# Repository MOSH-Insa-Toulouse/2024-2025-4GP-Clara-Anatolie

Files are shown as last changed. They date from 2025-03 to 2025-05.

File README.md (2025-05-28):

# 2024-2025 : Projet de capteur low-tech en graphite - Anatolie Blanc & Clara Jeandenans

## SOMMAIRE

- [SOMMAIRE](#sommaire)
- [Contexte](#contexte)
- [Livrables](#livrables)
- [Matériel nécessaire](#matériel-nécessaire)
- [Simulation électronique du capteur sous LTSpice](#simulation-électronique-du-capteur-sous-ltspice)
- [Design du PCB sous KiCad](#design-du-pcb-sous-kicad)
- [Réalisation du shield](#réalisation-du-shield)
- [Code Arduino](#code-arduino)
- [Tentatives de résolution des problèmes](#tentatives-de-résolution-des-problèmes)
- [Application Android](#application-android)
- [Banc de test](#banc-de-test)
- [Datasheet](#datasheet)
- [Conclusions et analyse critique du projet](#conclusions-et-analyse-critique-du-projet)
- [Contacts](#contacts)

## Contexte

&nbsp;&nbsp;&nbsp;&nbsp;&nbsp;&nbsp;Dans le cadre de l'UF "Du capteur au banc de test" effectué en 4ème année au département du Génie Physique de l’INSA Toulouse, nous avons développé un dispositif permettant de mesurer la contrainte appliquée sur un capteur graphite. Ce dernier est basé sur l'article "Pencil Drawn Strain Gauges and Chemiresistors on Paper" (Cheng-Wei Lin*, Zhibo Zhao*, Jaemyung Kim & Jiaxing Huang). Il est simplement composé d'un bout de papier sur lequel on vient déposer du graphite à l'aide d'un crayon à papier. La couche de graphite est constituée de particules reliées entre elles. En déformant le papier, la disposition des particules varie. En fonction du sens de flexion du papier, la déformation peut être soit une traction soit une compression. Dans le cas d’une traction, les particules de graphique s’écartent, la résistance augmente. Dans le cas d’une compression, les particules se rapprochent et la résistance diminue. Ainsi donc, ce système granulaire subit une modification de résistance et de conductance selon la contrainte exercée. Grâce à cela, nous pouvons remonter à la déformation, telle une jauge de contrainte traditionnelle.

Afin de réaliser ce dispositif permettant la mesure de déformation à partir d'un capteur low-tech, il nous faut suivre différentes étapes : simulations électroniques, design du PCB, code arduino et réalisation de la datasheet.

Ici, nous faisons un point de tout ce qui a été fait dans le cadre de ce projet.

## Livrables

Plusieurs livrables sont attendus :

- **Un shield PCB connecté à une carte arduino UNO** avec différents composants : un capteur graphite, un amplificateur transimpédance, un module bluetooth, un écran OLED, un flex sensor commercial, un potentiomètre digital, un encodeur rotatoire. D'autres composants peuvent être implémentés. Nous avons opté pour l'ajout d'un servo motor ;
- **Un code arduino** qui gère les différents composants cités précédemments (mesures de contraintes, échanges bluetooth et OLED, potentiomètre digital et boutons) ;
- **Une application Android** (sous MIT App Inventor) interfaçant le PCB et le code Arduino correspondant;
- **Une datasheet du capteur** reprenant toutes ses caractéristiques ainsi que ses tests.

## Matériel nécessaire

Afin de réaliser notre dispositif électronique, nous avons eu besoin de :

*Pour le montage amplificateur transimpédance :*

- Résistances : une de 1 kΩ, une de 10 kΩ et deux de 100 kΩ - une troisième de 100 kΩ peut être prévue, mais peut aussi être substituée par une résistance variable (le potentiomètre digital), choix que l'on a fait ;
- Potentiomètre digital MCP41050 et son support ;
- Amplificateur opérationnel LTC1050 et son support ;
- Capacités : trois de 100 nF et une de 1 μF.

*Pour le reste du dispositif :*

- Arduino Uno et son câble d’alimentation ;
- Résistance : une de 47kΩ pour le flex sensor ;
- Module Bluetooth HC05 ;
- Ecran OLED de dimension 128*64 ;
- Flex sensor ;
- Servo motor ;
- Encodeur rotatoire ;
- Capteur graphite et 2 pinces crocodiles ;
- 20 sockets ;
- 35 headers.

## Simulation électronique du capteur sous LTSpice

&nbsp;&nbsp;&nbsp;&nbsp;&nbsp;&nbsp;Notre capteur de graphite possède une résistance variable de l'ordre du gigaohm. Le courant généré, lorsque l'on applique une tension de 5V aux bornes du capteur, est très faible (de l'ordre de la dizaine de nanoampères). Ainsi, pour récupérer et pouvoir analyser ce signal, nous devons d’abord l'amplifier. C'est pourquoi nous avons utilisé un montage transimpédance, constitué d'un amplificateur opérationnel (AOP) pour fournir un signal en tension suffisant au convertisseur analogique-numérique (ADC) d'une carte Arduino UNO.

***Description du montage amplificateur transimpédance***

Nous avons testé ce montage sur le logiciel LTspice :

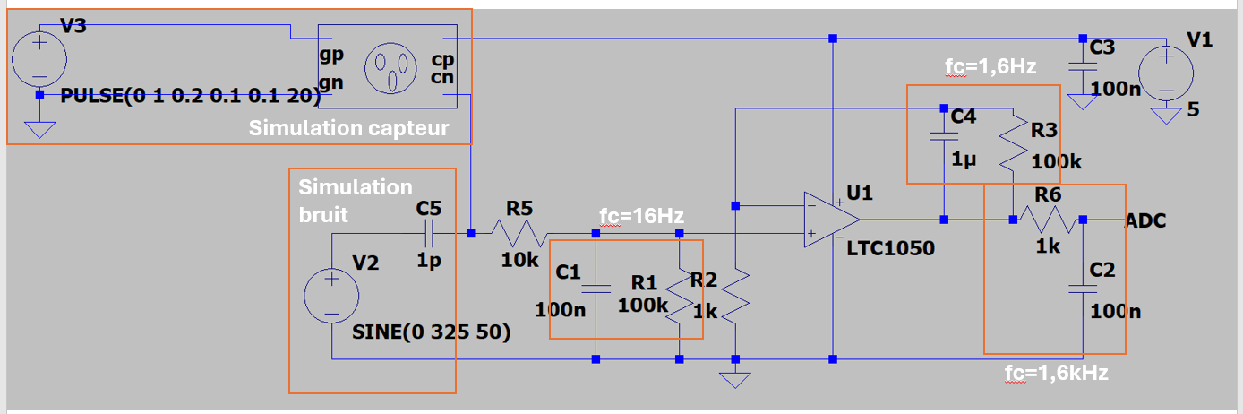
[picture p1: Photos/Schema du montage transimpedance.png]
montage_capteur_graphite


Pour construire ce montage, nous nous sommes basées sur ce schéma ci :

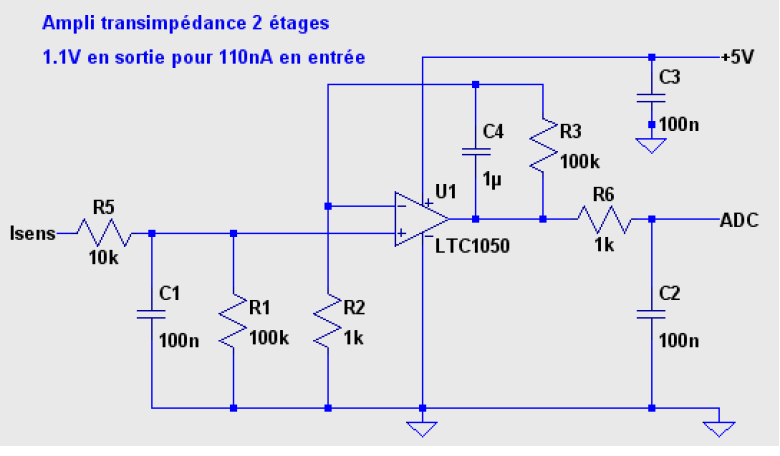
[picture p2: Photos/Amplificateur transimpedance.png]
montage_transimpédance


Concernant le choix de notre AOP, celui-ci devait être capable d'accepter en entrée un très faible courant. Il doit également avoir un offset de tension très faible afin de ne pas fausser les valeurs de tension transmises à l'ADC, puis analysées. Ainsi, nous avons choisi l’AOP nommé LTC 1050.

A ce circuit amplificateur, nous avons ajouté trois filtres pour améliorer notre signal :

- à l'entrée, un filtre passe-bas passif (R5,C1) ayant une fréquence de coupure de 16 Hz. Il permet de filtrer les bruits en courant sur le signal sortant du capteur ;
- un deuxième filtre passe-bas ayant une fréquence de coupure de 1.6 Hz (R3,C4) couplé à l'AOP. Ce filtre actif permet de filtrer la composante du bruit à 50 Hz provenant du réseau électrique ;
- à la sortie de l'amplificateur, un dernier filtre (R6,C2) ayant une fréquence de coupure de 1.6 kHz et permettant de filtrer le bruit lié au traitement opéré par l'amplificateur (bruits des alimentation, de l'horloge, etc...).

De plus, nous avons placé la capacité C3 de sorte à ce qu'elle filtre le bruit de l'alimentation. La résistance R5 en entrée, en plus de former avec la capacité C1 un filtre éliminant les bruits en tension, protège l'AOP contre les décharges électrostatiques. La résistance R1 sert de résistance de shunt entre la source de courant et la masse. La résistance R2 sera remplacé plus tard par un potentiomètre digital afin de régler le gain de l’AOP en fonction de nos besoins.

***Simulations réalisées sous LTSpice***

Pour savoir si nos filtres étaient efficients, nous avons testé notre circuit le logiciel LTSpice, en deux temps.
D'abord, nous avons effectué une première simulation en régime transitoire pour vérifier que l'amplification soit bien effective. Voici la réponse obtenue :

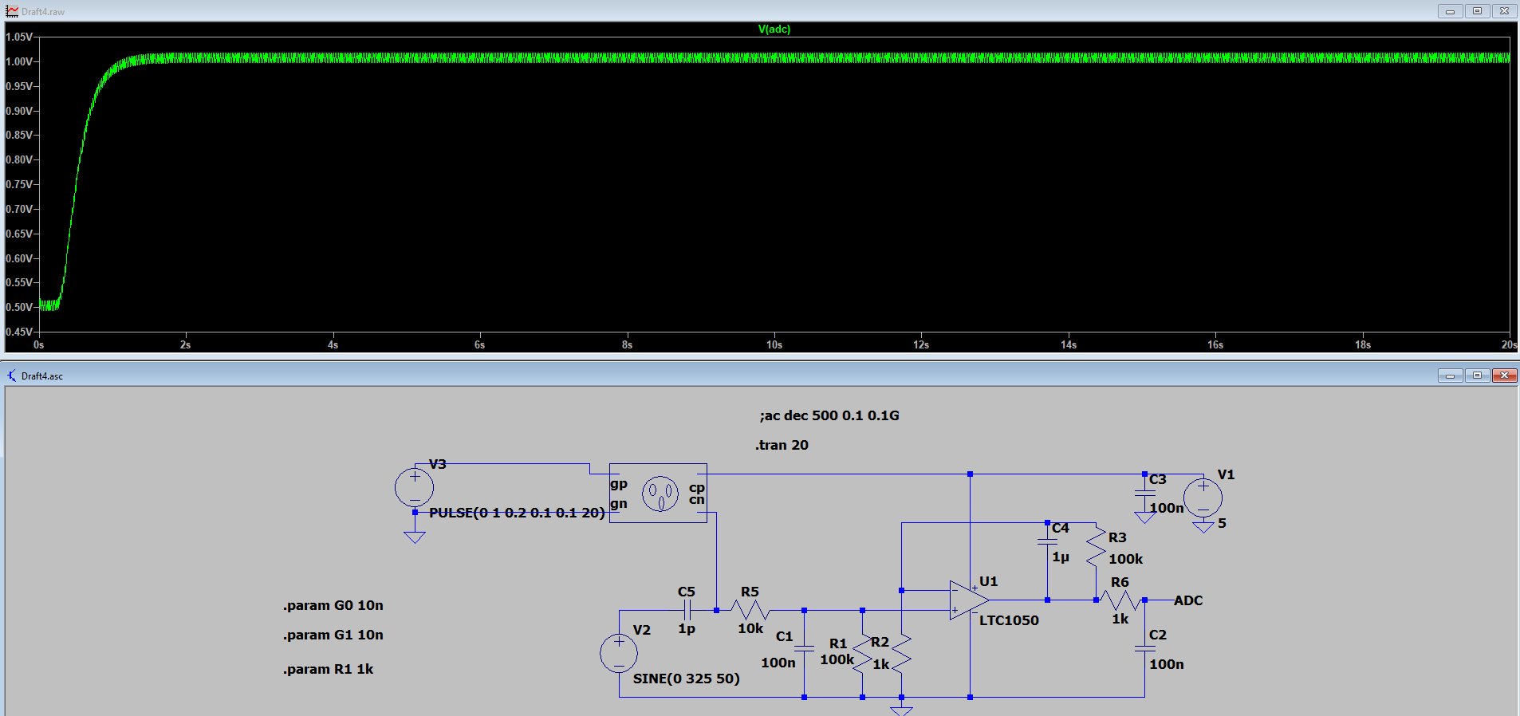
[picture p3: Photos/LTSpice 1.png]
Test_En_Transitoire


Comme on peut le constater sur le graphe, le signal est bien amplifié à 1 V. L'Arduino pourra donc l'interpréter.

Ensuite, nous avons effectué une seconde simulation, afin d'observer la réponse à un courant alternatif et ainsi de vérifier que le signal est bien filtré.

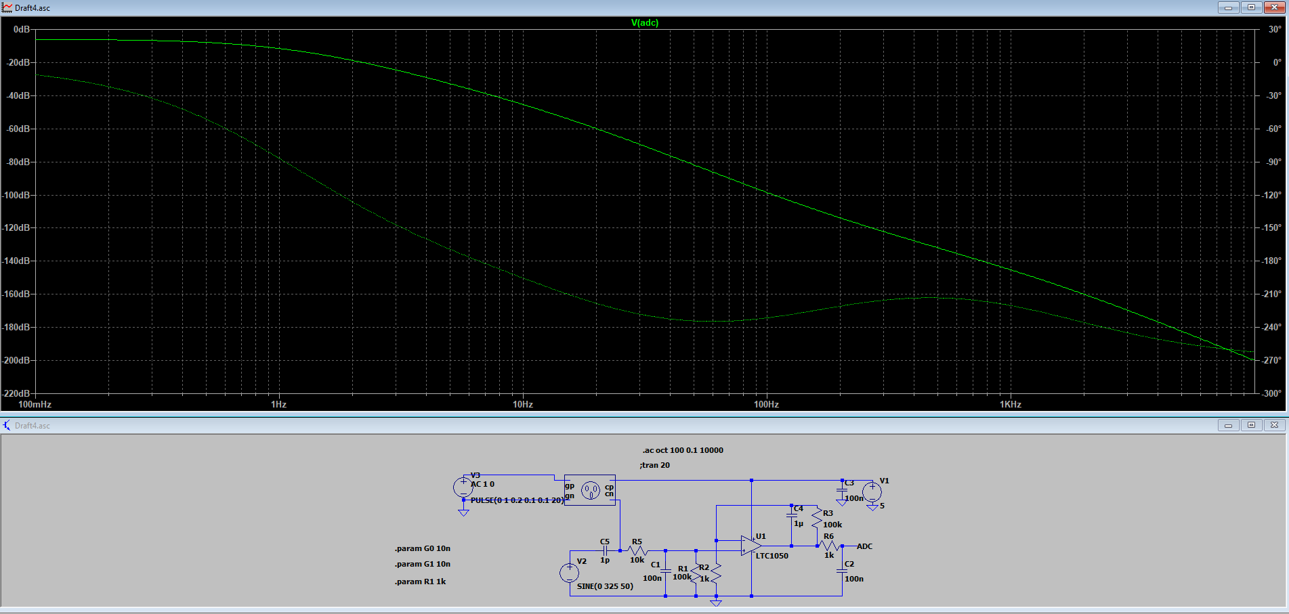
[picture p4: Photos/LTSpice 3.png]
Test_En_AC


Comme on peut le constater ci-dessous, le signal paraît être filtré successivement par les 3 filtres. Le bruit est atténué d’environ 72dB à 50Hz. Le montage est performant.

## Design du PCB sous KiCad

&nbsp;&nbsp;&nbsp;&nbsp;&nbsp;&nbsp;Afin de réaliser notre PCB, nous avons reproduit le circuit précédent sur Kicad 9.0. Nous avons remplacé la résistance R2 par un potentiomètre numérique afin de pouvoir faire varier le gain de notre AOP. De plus, nous avons rajouté divers composants afin de pouvoir mesurer efficacement la valeur de notre capteur graphite et comparer les résultats obtenus :

- un flexsensor servant de témoin, afin de pouvoir comparer nos mesures avec celle du capteur graphite
- un module bluetooth HC-05 afin de pouvoir communiquer avec notre circuit depuis notre téléphone depuis une application mobile que avons codée nous-même
- un écran OLED ainsi qu’un encodeur rotatoire pour pouvoir visualiser le résultat de nos mesures et pouvoir naviguer simplement dans les différents menus servant à réaliser diverses mesures
- un servomotor.

Tous nos composants ont été installés sur un shield d'Arduino UNO.

Nous avons débuté par la création d'une librairie de symboles comportant tous les différents composants. Puis, nous avons procédé à la réalisation de la schématique électrique de l'ensemble du montage sur Kicad. Voici le schéma électrique de l'ensemble de notre montage :

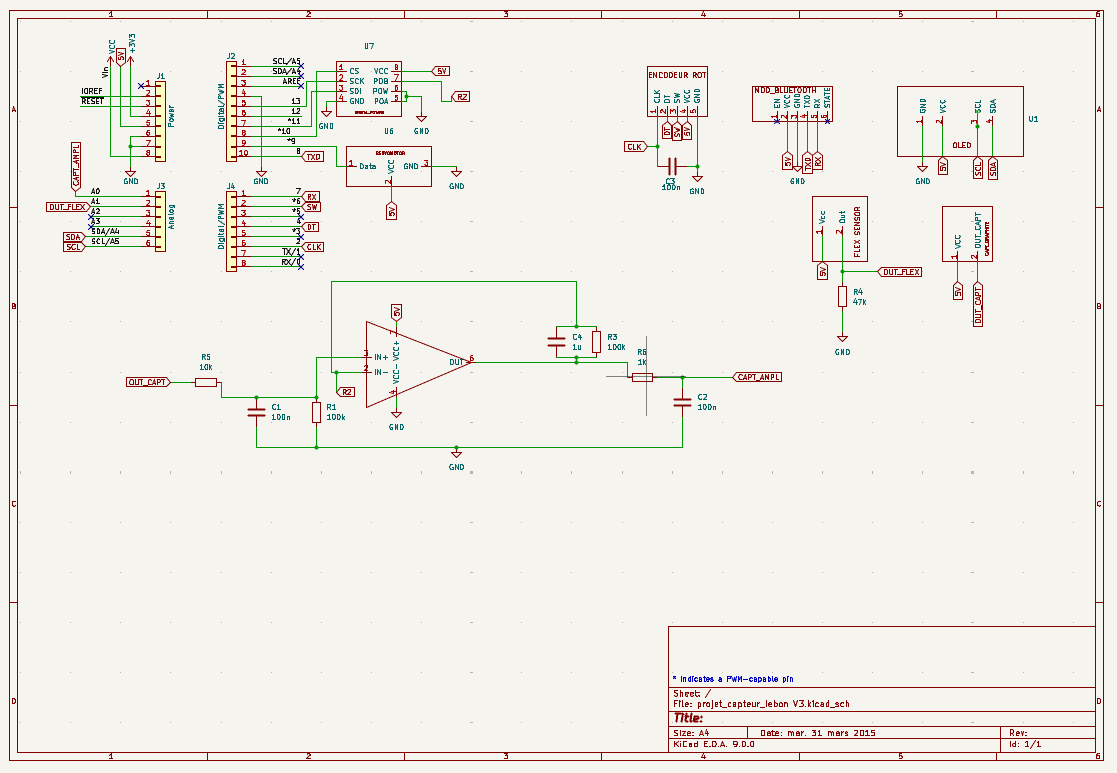
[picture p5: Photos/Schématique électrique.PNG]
Schema_elec_Kicad


Nous avons ensuite réalisé les empreintes de nos composants en respectant certaines dimensions, en vue de l'impression du PCB (diamètre des trous, forme des empreintes, etc.).Nous sommes ensuite passées à la disposition des composants sur le PCB : une étape complexe car il faut faire des compromis afin d'obtenir le placement le plus efficace (en considérant les connexions entre composants, en évitant d'avoir recours aux vias, etc.). L'image ci-dessous correspond au résultat final de notre PCB :

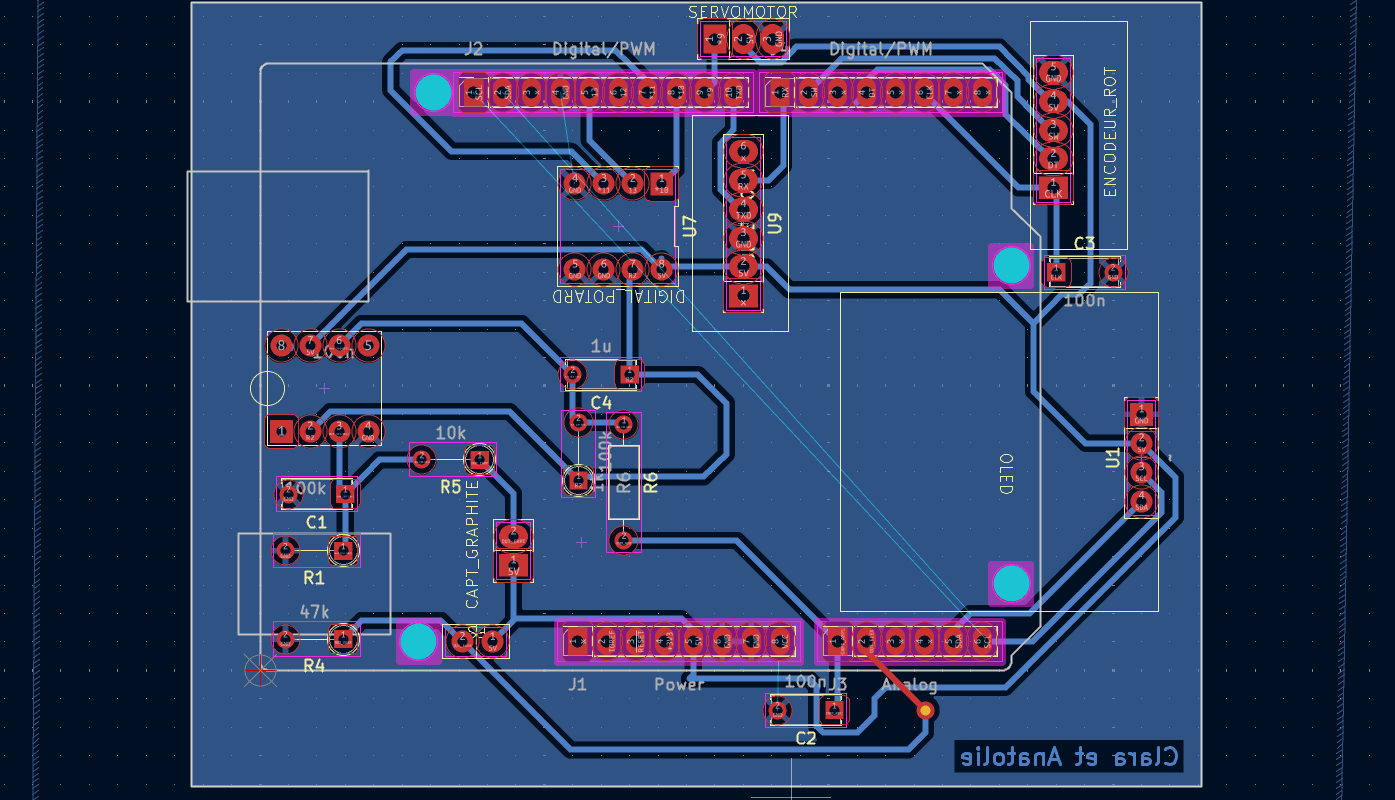
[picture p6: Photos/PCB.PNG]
PCB_Kicad


Nous avons aussi fait en sorte que les composants ne se touchent pas à l’aide du rendu 3D que voici :

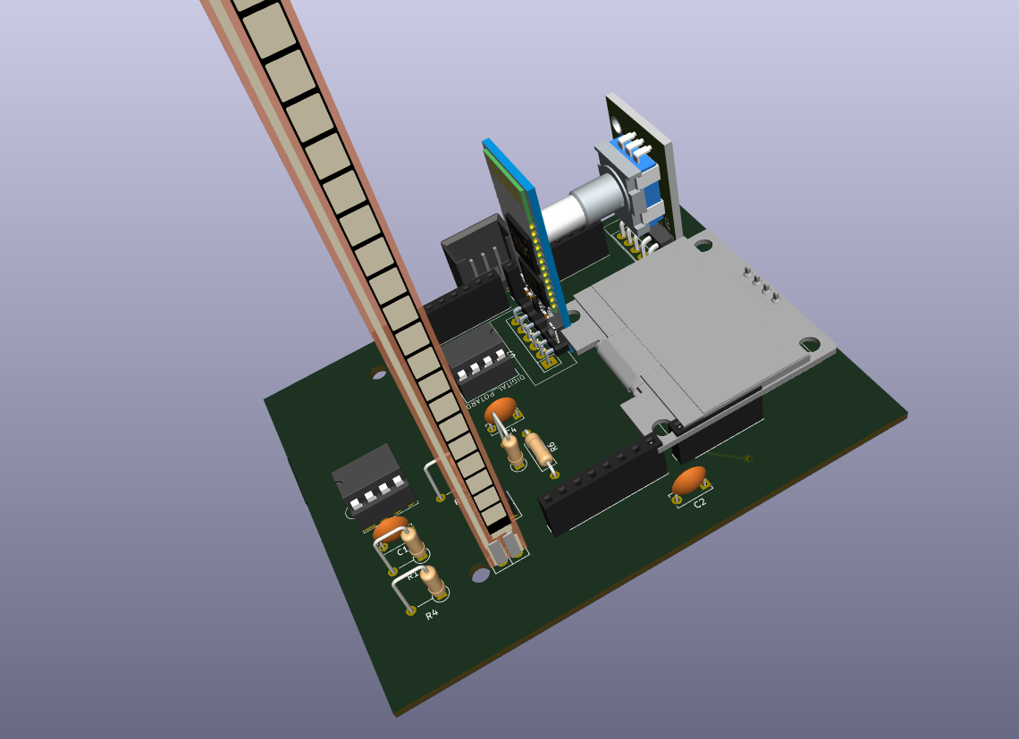
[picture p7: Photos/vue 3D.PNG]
3D_PCB_Kicad


Les fichiers KiCad sont disponibles dans le dossier [KiCad](https://github.com/MOSH-Insa-Toulouse/2024-2025-4GP-Clara-Anatolie/tree/3c948c7d110ff542ae939aa06793f8daed436087/KiCad/projet_capteur_lebon%20-%20VERSION%203)

## Réalisation du shield

&nbsp;&nbsp;&nbsp;&nbsp;&nbsp;&nbsp;Une fois notre PCB réalisé sur Kicad, nous avons pu passer à la réalisation physique de notre PCB. Voici les étapes de fabrication réalisées, avec l'aide de Cathy Crouzet (un grand merci à elle qui a pris le temps de tirer notre PCB et nous expliquer le processus de fabrication !) :

- Étape 0 (importante !) : vérification du PCB sous KiCad ;

- Étape 1 : édition du masque de gravure de notre PCB sous KiCad ;

- Étape 2 : insolation UV d'une plaquette d'époxy recouverte d'une couche de cuivre et de résine photosensible ;

- Étape 3 : immersion de la plaquette dans un révélateur afin d'éliminer la résine non-insolée ;

- Étape 4 : immersion de la plaquette dans du perchlorure de fer pour graver les pistes ;

- Étape 5 : nettoyage de la plaquette avec de l'acétone pour retirer la résine restante.

Nous avons ensuite pu réaliser le perçage de notre plaquette et y souder nos divers composants selon le schéma du PCB obtenu sur Kicad.

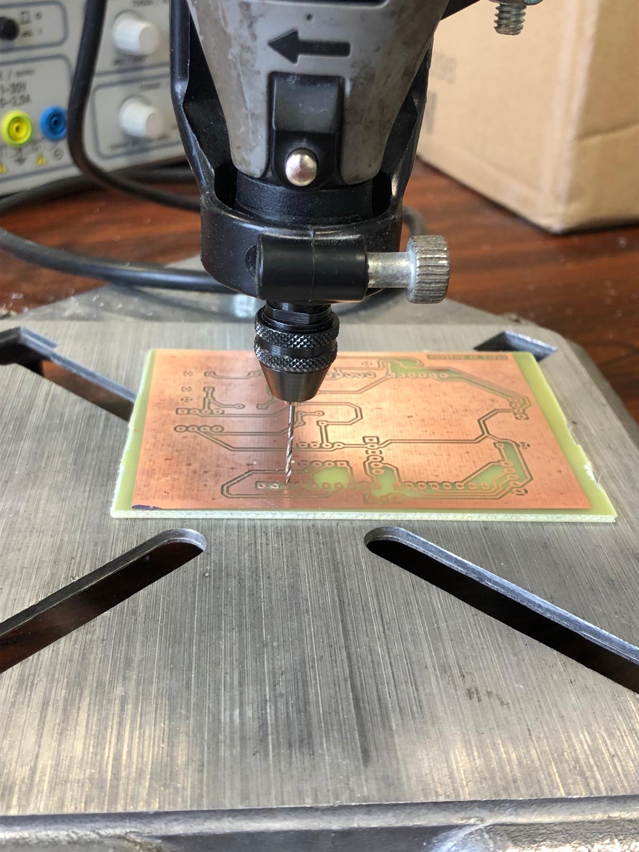
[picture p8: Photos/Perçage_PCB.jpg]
Perçage_du_PCB


Voici le résultat final de notre PCB :

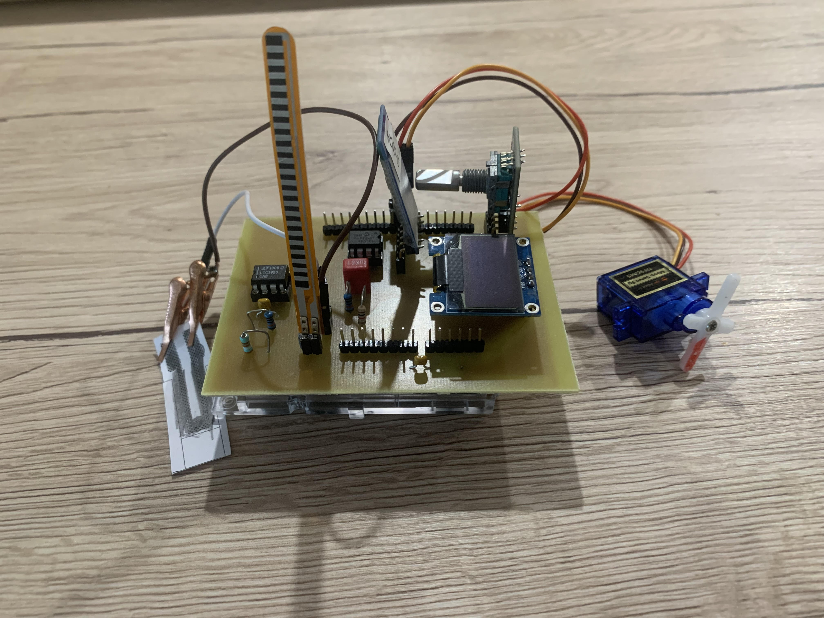
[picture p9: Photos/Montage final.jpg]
Plaquette_finale


L’assemblage de la plaquette et l’Arduino a été plus compliqué que prévu. En effet, l'ensemble de nos trous étaient légèrement décalés les uns par rapport aux autres. Le problème semblait venir de l’étape de perçage.

De plus, le header connecté à la pin A0, qui devait servir pour le capteur de graphite, ne fonctionne pas. Nous avons donc décidé d'utiliser la pin A1, qui servira donc à récupérer les données du flex sensor et du capteur de graphite. Il nous suffit alors de brancher/débrancher les capteurs pour les échanger. Malheureusement, le signal provenant du capteur de graphite ne sera donc pas filtré et amplifié.

## Code Arduino

&nbsp;&nbsp;&nbsp;&nbsp;&nbsp;&nbsp;Nous avons utilisé l'IDE Arduino 2.3.4 . Plusieurs fichiers de test sont disponibles dans le [dossier Arduino](https://github.com/MOSH-Insa-Toulouse/2024-2025-4GP-Clara-Anatolie/tree/main/Code%20Arduino/Codes_Arduino_Tests).

Pour le [fichier principal](https://github.com/MOSH-Insa-Toulouse/2024-2025-4GP-Clara-Anatolie/tree/main/Code%20Arduino/Projet_capteur), nous avions prévu de faire une calibration du potentiomètre digital en fonction de la valeur mesurée par le capteur graphite. Ensuite, le menu de l'écran OLED propose 3 options :
- Utiliser le flex sensor
- Utiliser le capteur graphite
- Utiliser le Servo moteur

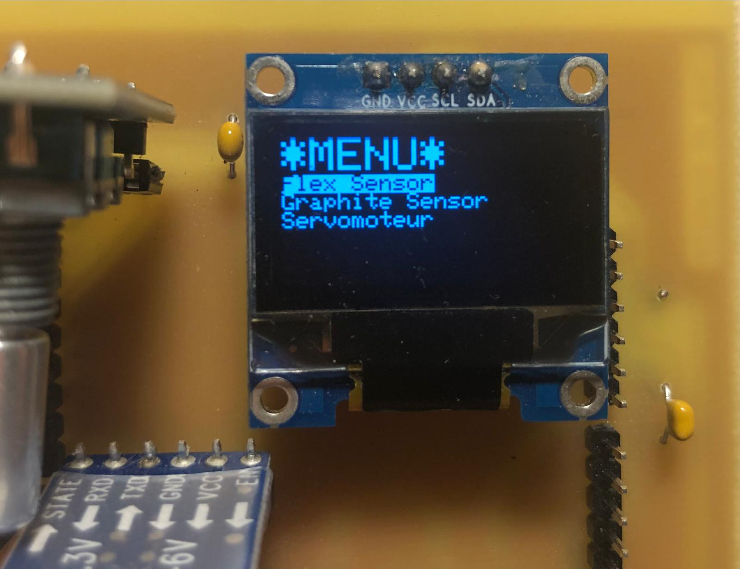
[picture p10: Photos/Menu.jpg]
Menu


Le choix se fait grâce à l'encodeur rotatoire. En tournant, on peut passer sur les différentes options puis en sélectionner une en appuyant sur l'encodeur. Cet appui sert également à sortir du menu selectionné.

L'option concernant le flex sensor récupère sa valeur et l'écrit sur l'OLED. L'option "Graphite Sensor" récupère sa valeur de résistance et l'affiche aussi sur l'écran. Enfin, la dernière option déplace le servo moteur en fonction de la valeur du flex sensor.

Le calcul de la résistance du capteur en graphite se fait avec la formule : $Res=R1*(1+\frac{R3}{R2})*\frac{Vcc}{Vadc}-R1-R5$

Dans notre cas, la résistance R2 est variable : c'est celle du potentiomètre digital qui est calculé avec : $R2=\frac{47500*pos}{256}+125$, où $47500$ correspond à la valeur de résistance maximale de notre MCP41050 et $pos$ la position du potentiomètre parmi les 256 valeurs.

Le module bluetooth HC-05 reçoit également les valeurs du capteur graphite et affiche un graphe.

## Tentatives de résolution des problèmes

&nbsp;&nbsp;&nbsp;&nbsp;&nbsp;&nbsp;Lorsque nous tentons de récupérer la valeur de la résistance du capteur graphite, nous obtenons une valeur infinie. En effet, la tension de sortie de ce capteur est nulle. Nous avons vérifié toutes les connexions sur le PCB à l'aide d'un multimètre. Nous avons également vérifié les valeurs des résistances et changé les composants. Nous avons aussi essayé de remplacer le potentiomètre par une résistance fixe de 1 kOhms, le capteur graphite par une résistance fixe de 100 MOhm et le PCB par une breadboard. Enfin, nous avons essayé diférents programmes, qui donnaient tous le meme resultat. Nous n'avons pas réussi à identifier le problème et nous avions déjà passé beaucoup de temps dessus alors nous  avons décidé d'utiliser le pin A1, celui du flex sensor, pour récupérer les valeurs du capteur graphite.

## Application Android

Une application a été développée sous [MIT App Inventor](https://appinventor.mit.edu/). Elle fonctionne lorsque l'on entre dans le menu "Flex Sensor", sur le menu principal. Nous avons mis un bouton permettant de sélectionner l'appareil connecté au bluetooth, une zone de lecture de la valeur de la résistance mesurée, ainsi qu'un graphe permettant de voir l'évolution temporelle de cette valeur. Un dernier bouton permet d'écrire la valeur 10 dans le serial monitor, afin de tester l'envoi de données de l'application vers le dispositif bluetooth. Nous n'avons malheureusement pas eu le temps de développer plus l'application, souhaitant résoudre le problème du capteur graphite.

L'interface utilisateur de l'application :

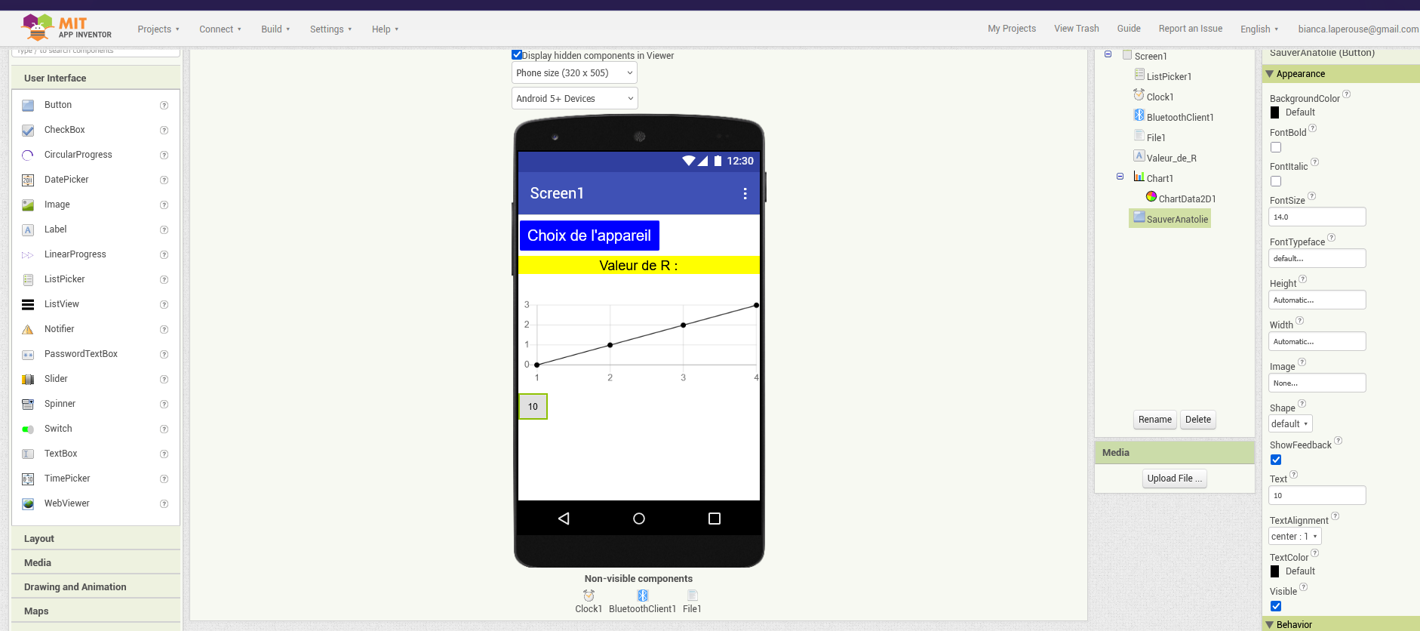
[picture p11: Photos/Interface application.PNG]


La face arrière de l'application :

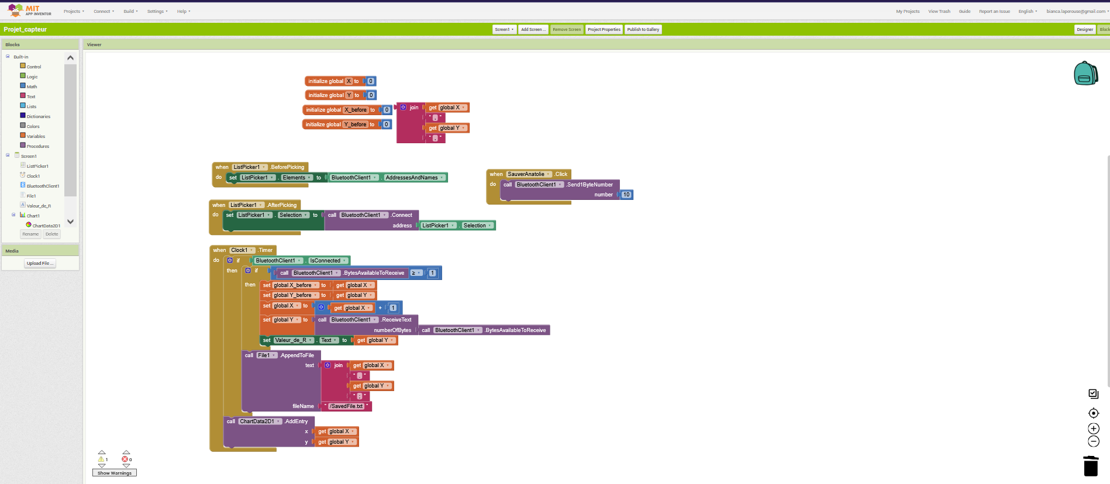
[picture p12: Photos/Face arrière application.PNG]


Un test réalisé avec le flex sensor :

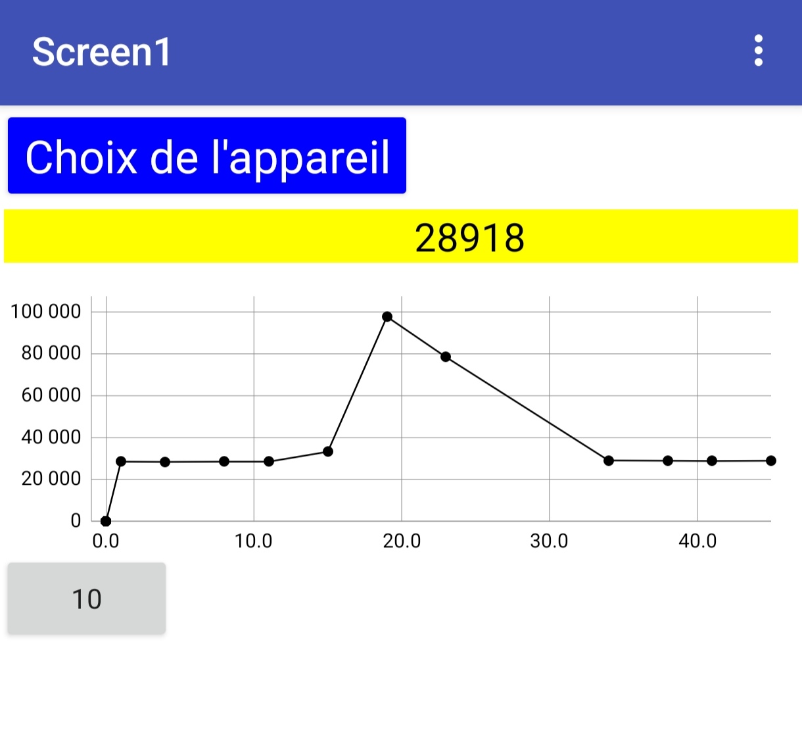
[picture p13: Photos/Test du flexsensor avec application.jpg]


Le QR code pour télécharger l'application : 

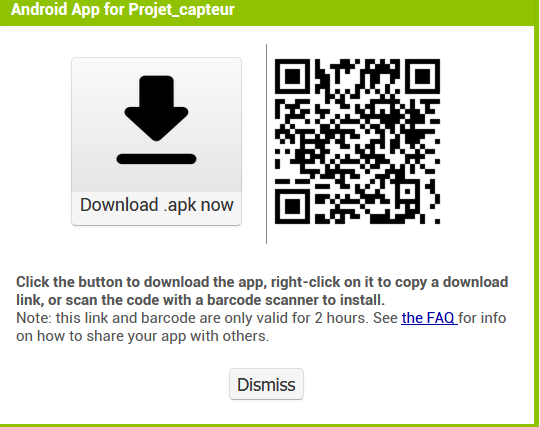
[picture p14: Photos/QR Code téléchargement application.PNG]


## Banc de test

&nbsp;&nbsp;&nbsp;&nbsp;&nbsp;&nbsp;Pour caractériser notre capteur et son montage, nous avons décidé d'utiliser des demi-cercles avec des rayons de courbure différents. Grâce à ces demi-cercles, nous avons pu calculer la variation de la résistance électrique $\frac{\Delta R}{R_0}$ en fonction de la déformation $\epsilon=\frac{e}{D}$. Nous avons ici mesuré notre épaisseur de notre papier e = 0.2 mm.

Voici les courbes obtenues :

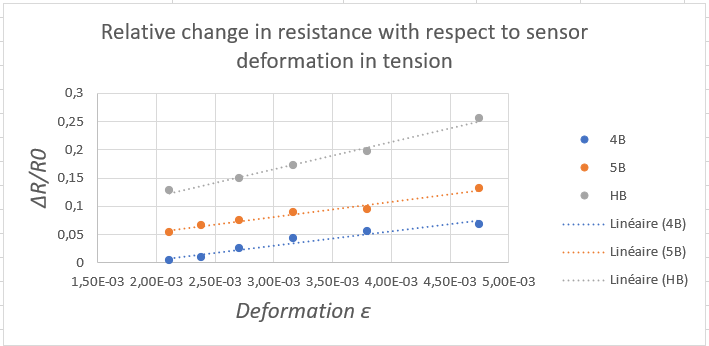
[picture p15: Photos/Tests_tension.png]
Tests_tension


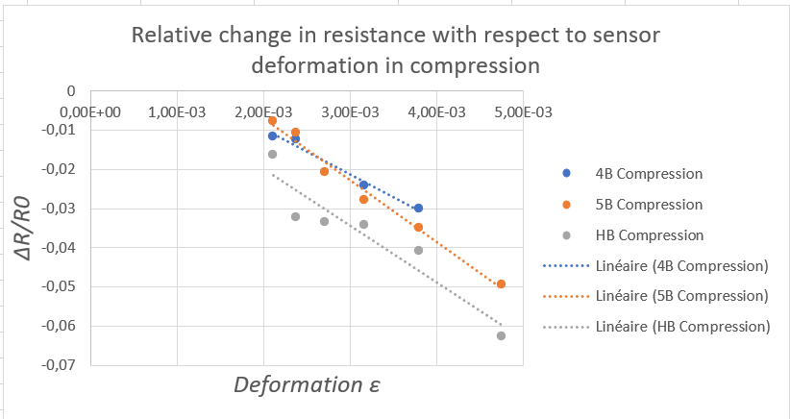
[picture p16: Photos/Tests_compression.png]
Tests_compression


Nous remarquons que la résistance augmente lorsque l'on met le capteur en tension et qu'elle diminue lors de la compression. En tension, la distance entre les atomes augmente et la résistance augmente avec. Le contraire se produit pour la compression.

En fonction du type de crayon utilisé, les variations relatives de résistance changent. Plus le crayon est gras (2H->H->HB->B->2B avec 2B contenant le plus de carbone), moins sa variation relative de résistance est élevée.

Enfin, on peut comparer notre capteur avec un flex sensor commercial. Il semblerait que le flex sensor soit plus sensible à la déformation, en plus d'être plus solide pour des déformations importantes. Cepndant, le capteur graphite a un nombre d'utilisation très limité.

De plus, nos mesures ne sont pas forcément reproductibles car elles dépendent fortement de la quantité de crayon déposé. Ainsi, la résistance varie beaucoup d'un capteur à un l'autre.

## Datasheet

La datasheet de notre capteur est disponible [ici](Datasheet).

## Conclusions et analyse critique du projet

&nbsp;&nbsp;&nbsp;&nbsp;&nbsp;&nbsp;Ce projet a été très enrichissant. En menant un projet de bout en bout, des simulations à la datasheet, nous avons pu avoir un avant goût du travail d'ingénieur. Nous avons aussi pu avoir une vision des nombreuses compétences (simulation électronique, développement informatique, design d'un montage électronique, fabrication physique de ce dernier, etc.) indispensables à un ingénieur de nos jours. En ce sens, c'est un projet qui a donc été assez professionnalisant. De  plus, il est gratifiant de pouvoir fabriquer un produit dans son entièreté et de le voir fonctionner.

En ce qui concerne le capteur graphite fabriqué, il n'est malheureusement pas fonctionnel pour nous, malgré toutes nos tentatives de compréhension du problème. Les tests avec la pin du flex sensor nous permettent de dégager des tendances à peu près cohérentes avec la physique. Cependant, les conditions de tests étant rudimentaires, peu reproductibles et non flitrées dans notre cas, cela conduit à des résultats assez aléatoires. Il est donc nécessaire de prendre du recul sur leur véracité.

## Contacts

&nbsp;&nbsp;&nbsp;&nbsp;&nbsp;&nbsp;Pour toute information complémentaire, vous pouvez nous contacter à ces adresses mails :

- Anatolie Blanc : <anatolie.blanc@insa-toulouse.fr>
- Clara Jeandenans : <clara.jeandenans@insa-toulouse.fr>

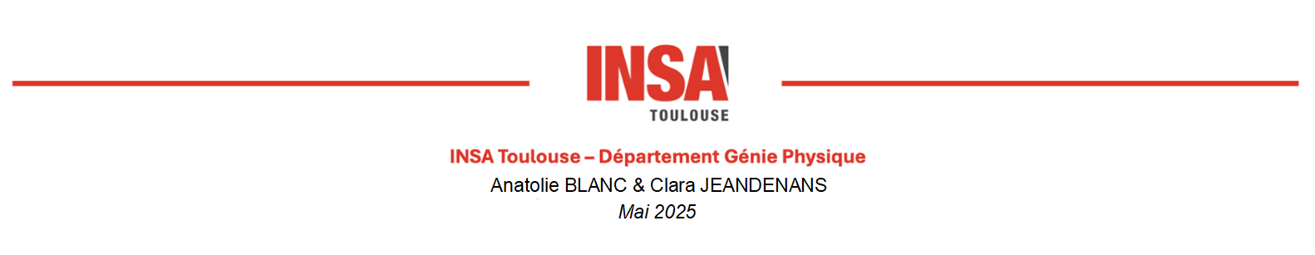
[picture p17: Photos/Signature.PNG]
Signature


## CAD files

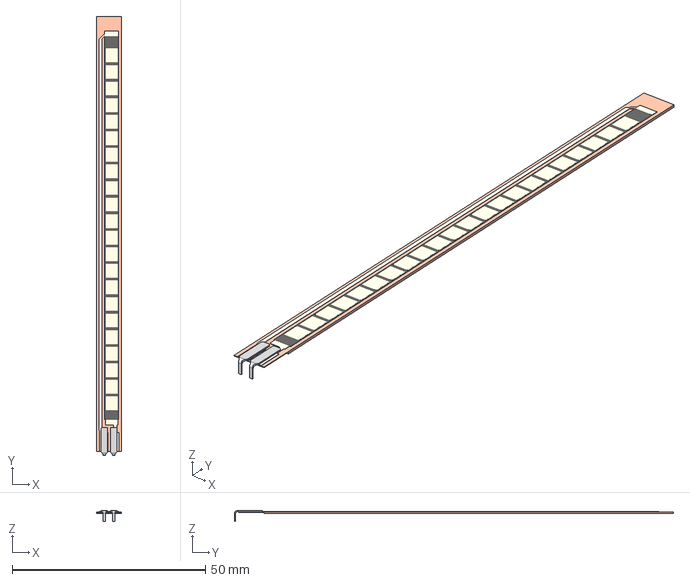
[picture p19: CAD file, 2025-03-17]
KiCad/Modele 3D/FS-L-0095-103-ST - Assembly.stp
6.45 x 113.5 x 2.77 mm
FS-L-0095-103-ST - Base
FS-L-0095-103-ST - Top

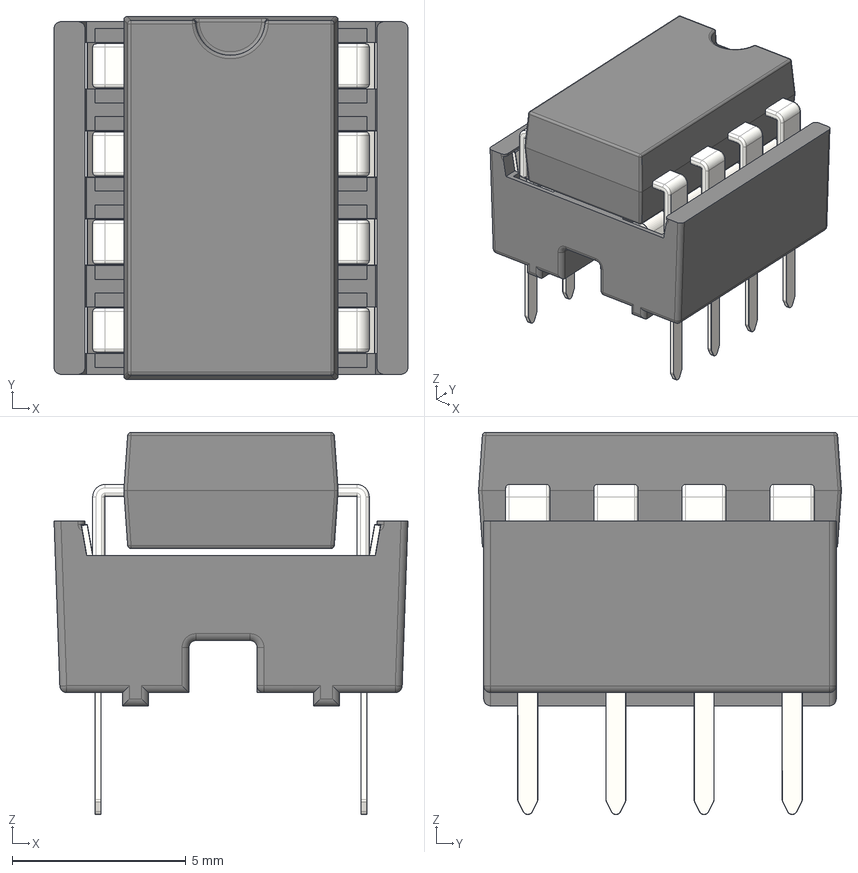
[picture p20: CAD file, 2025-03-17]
KiCad/Modele 3D/DIP-8 W7.62mm IC with Socket.stp
10.2 x 10.5 x 11.0 mm
Stamped Dual Wipe Contact for DIP Sockets x 8
Body DIP-8 P7.62mm Socket
IC Beinchen x 8
DIP-8 W7.62

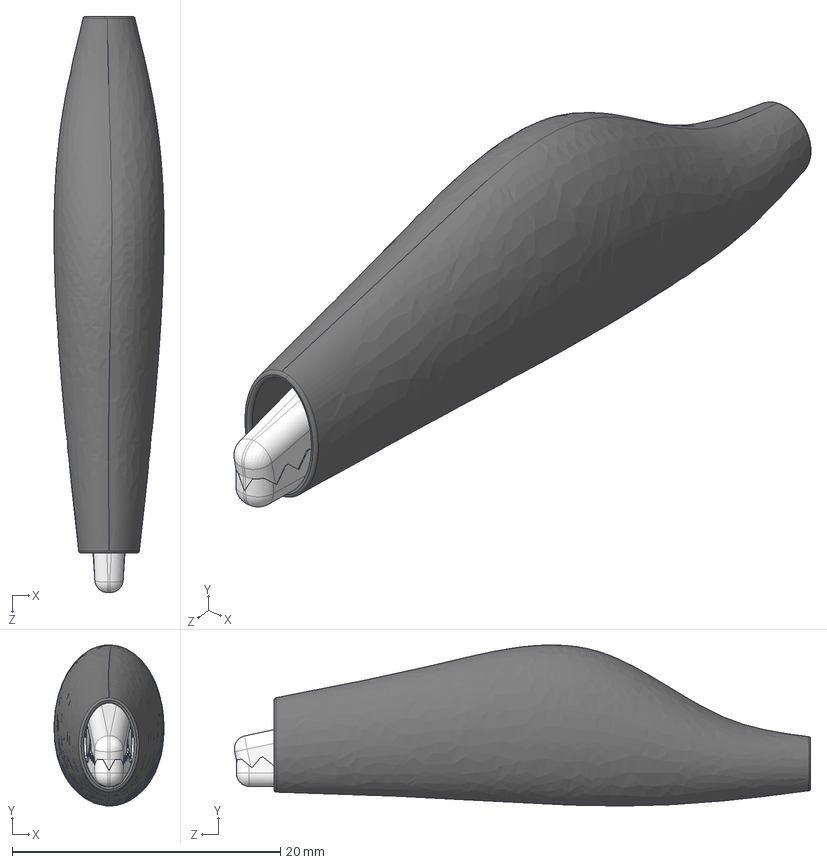
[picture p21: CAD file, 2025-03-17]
KiCad/Modele 3D/Crocodile Clip & Black Insulator.STEP
8.19 x 12.0 x 42.9 mm
Crocodile clip_01
Crocodile clip_02
Silicone Insulator_BLACK

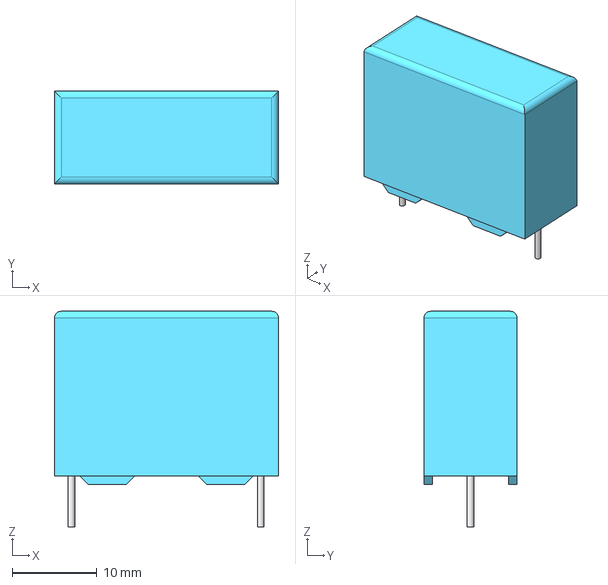
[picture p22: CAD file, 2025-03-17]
KiCad/Modele 3D/Cap_Rect.step
26.5 x 11.0 x 25.5 mm

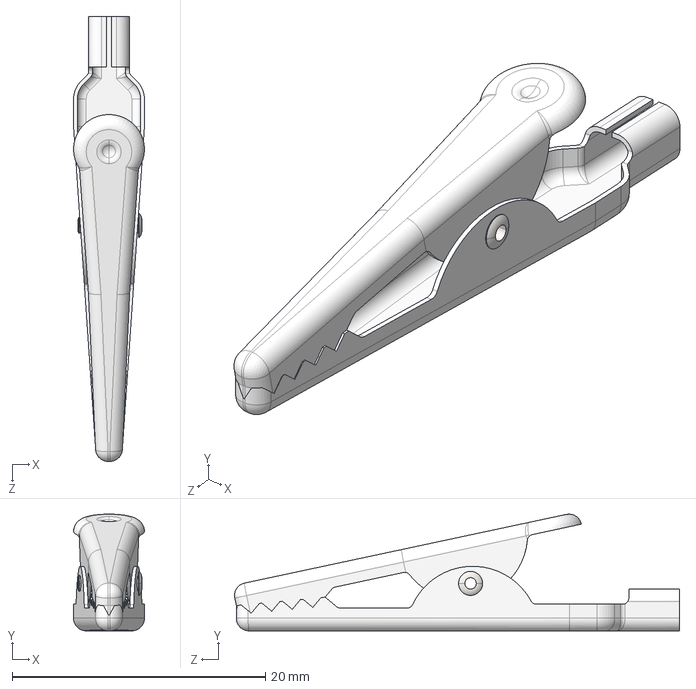
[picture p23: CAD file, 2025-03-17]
KiCad/Modele 3D/Crocodile Clip.STEP
5.60 x 9.22 x 35.1 mm
Crocodile clip_01
Crocodile clip_02

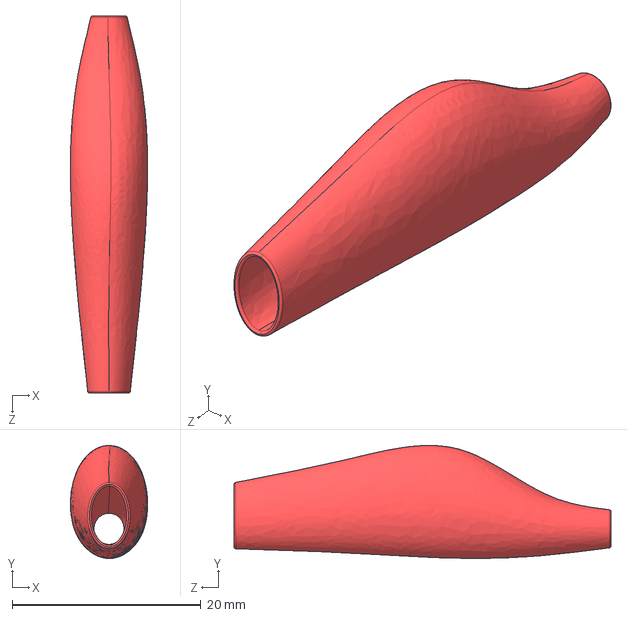
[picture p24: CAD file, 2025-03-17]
KiCad/Modele 3D/Silicone Insulator_RED.STEP
8.19 x 12.0 x 40.0 mm

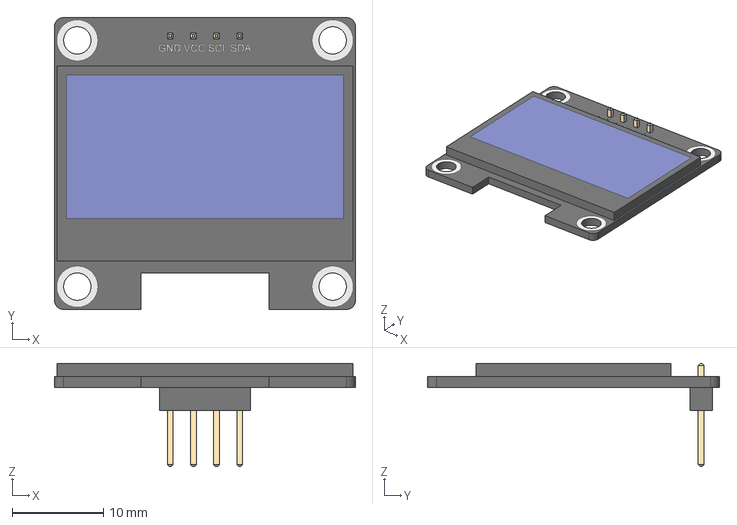
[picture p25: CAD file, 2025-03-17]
KiCad/Modele 3D/SSD1315 ZhongJingYuan v1.step
33.0 x 32.0 x 11.3 mm

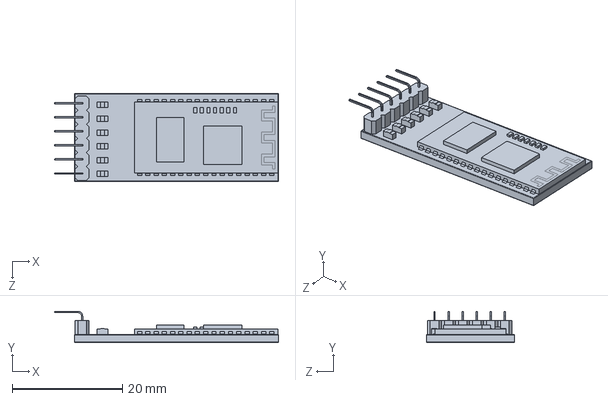
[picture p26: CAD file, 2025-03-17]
KiCad/Modele 3D/HC05.STEP
40.6 x 5.67 x 16.0 mm

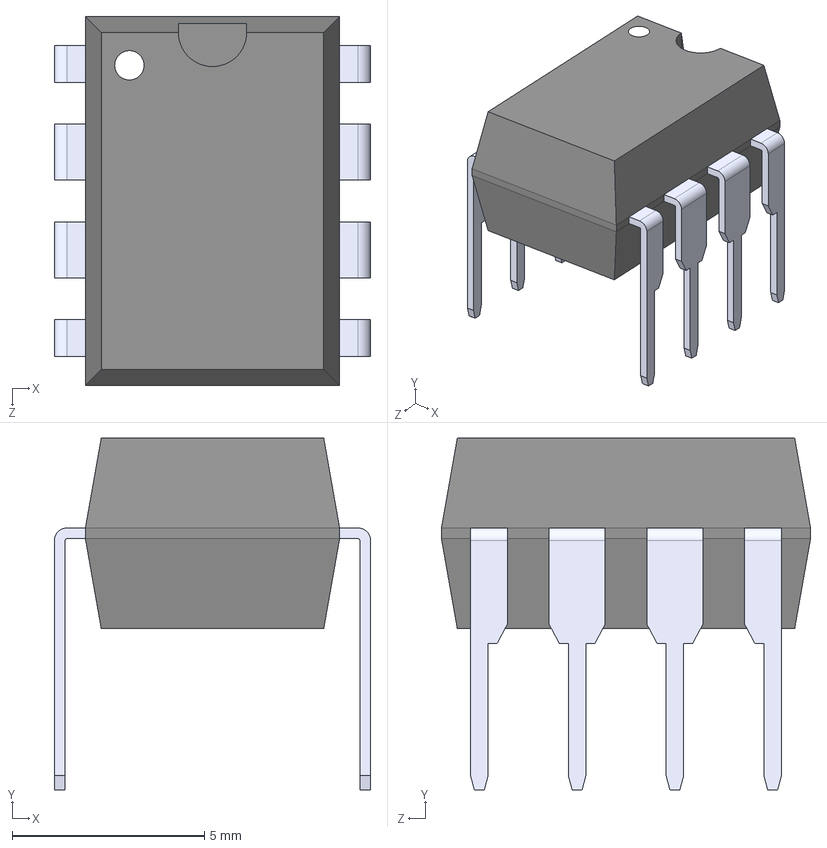
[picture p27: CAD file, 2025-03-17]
KiCad/Modele 3D/LTC1050ACN8.step
8.22 x 9.14 x 9.59 mm

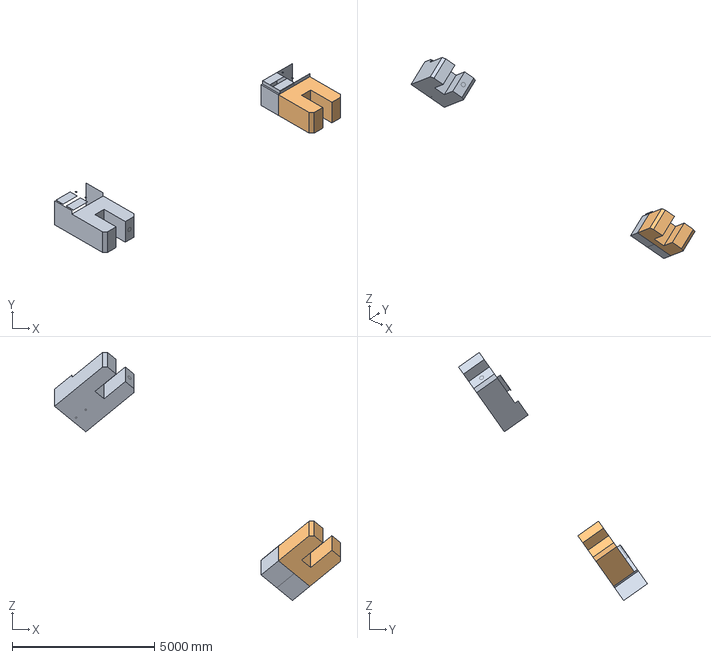
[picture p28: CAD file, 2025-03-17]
KiCad/Modele 3D/Design And Draft.dwg.STP
10038.5 x 6631.4 x 8709.7 mm

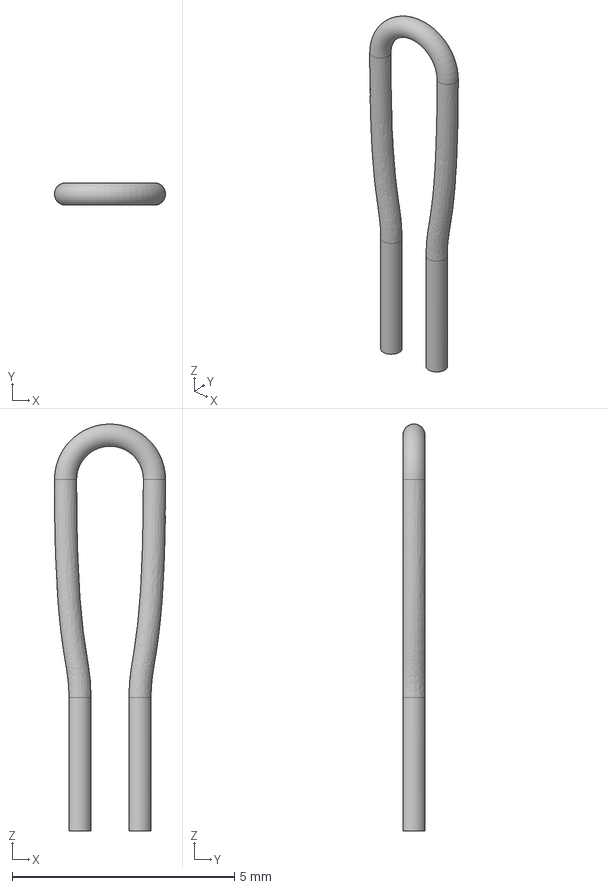
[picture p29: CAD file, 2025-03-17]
KiCad/Modele 3D/TestPoint_Loop_D2.50mm_Drill1.85mm.step
2.50 x 0.5 x 9.15 mm

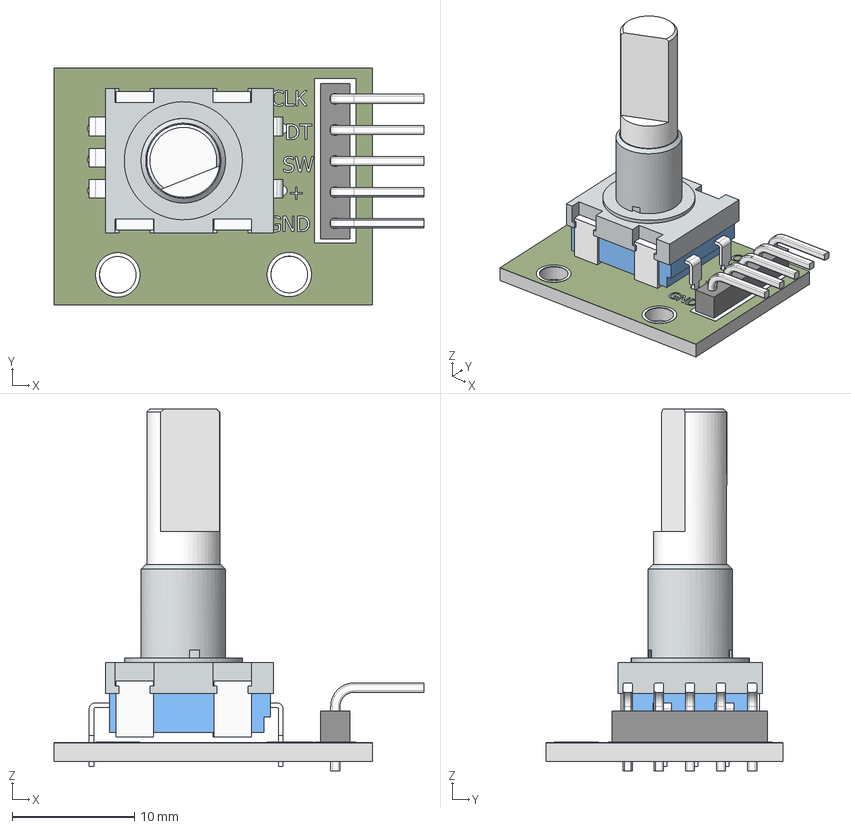
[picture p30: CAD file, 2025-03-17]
KiCad/Modele 3D/rotary+encoder_14mm_hole_spc.stp
30.2 x 19.3 x 29.6 mm
pcb
mtg flange
body_encoder
5 pin header
90d pin_header x 5
decal_encoder
pins_encoder body_2 x 5
shaft_encoder

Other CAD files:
KiCad/Modele 3D/Silicone Insulator_BLACK.STEP
KiCad/Modele 3D/Crocodile Clip & RED Insulator .STEP

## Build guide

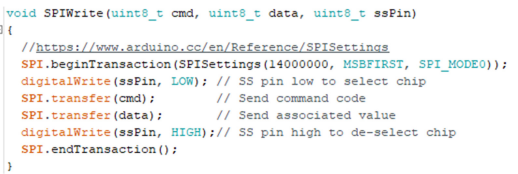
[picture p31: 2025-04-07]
Code Arduino/Codes_Arduino_Tests/setup spi.PNG

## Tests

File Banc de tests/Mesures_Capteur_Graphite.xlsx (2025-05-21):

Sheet: 4B tension
Cylindre utilisé (déformation croissante) | R courbure | Déformation associée | R mesurée (ohm) | ΔR | |ΔR|/R0
Aucun, R0 | inf | 0 | 27209 | 0 | 0
1 | 0.045 | 0.00211 | 27338 | 129 | 0.00474107832
2 | 0.04 | 0.00238 | 27449 | 240 | 0.008820610827
3 | 0.035 | 0.00271 | 27894 | 685 | 0.0251754934
4 | 0.03 | 0.00317 | 28400 | 1191 | 0.04377228123
5 | 0.025 | 0.0038 | 28700 | 1491 | 0.05479804476
6 | 0.02 | 0.00475 | 29050 | 1841 | 0.06766143555

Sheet: 5B tension
Cylindre utilisé (déformation croissante) | R courbure | Déformation associée | R mesurée (ohm) | ΔR | |ΔR|/R0
Aucun, R0 | 1 | 0 | 117000 | 0 | 0
1 | 0.045 | 0.00211 | 123341 | 6341 | 0.0541965812
2 | 0.04 | 0.00238 | 124672 | 7672 | 0.06557264957
3 | 0.035 | 0.00271 | 125678 | 8678 | 0.07417094017
4 | 0.03 | 0.00317 | 127400 | 10400 | 0.08888888889
5 | 0.025 | 0.0038 | 128096 | 11096 | 0.09483760684
6 | 0.02 | 0.00475 | 132320 | 15320 | 0.1309401709
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

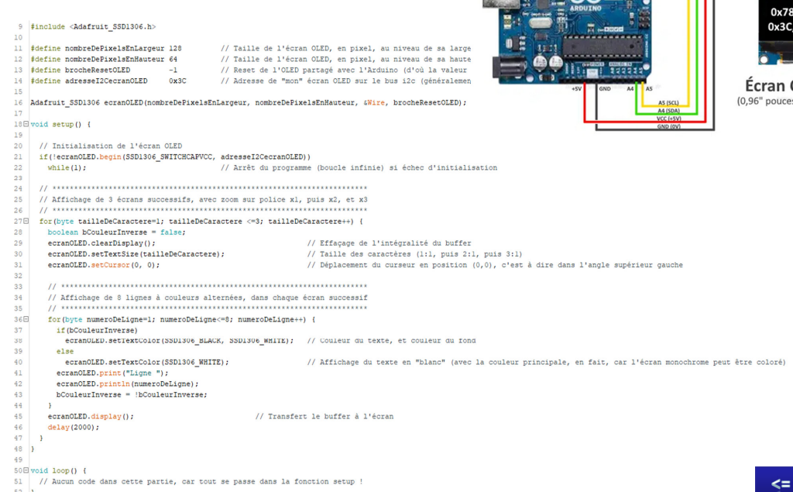
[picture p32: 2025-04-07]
Code Arduino/Codes_Arduino_Tests/oled/code oled.PNG

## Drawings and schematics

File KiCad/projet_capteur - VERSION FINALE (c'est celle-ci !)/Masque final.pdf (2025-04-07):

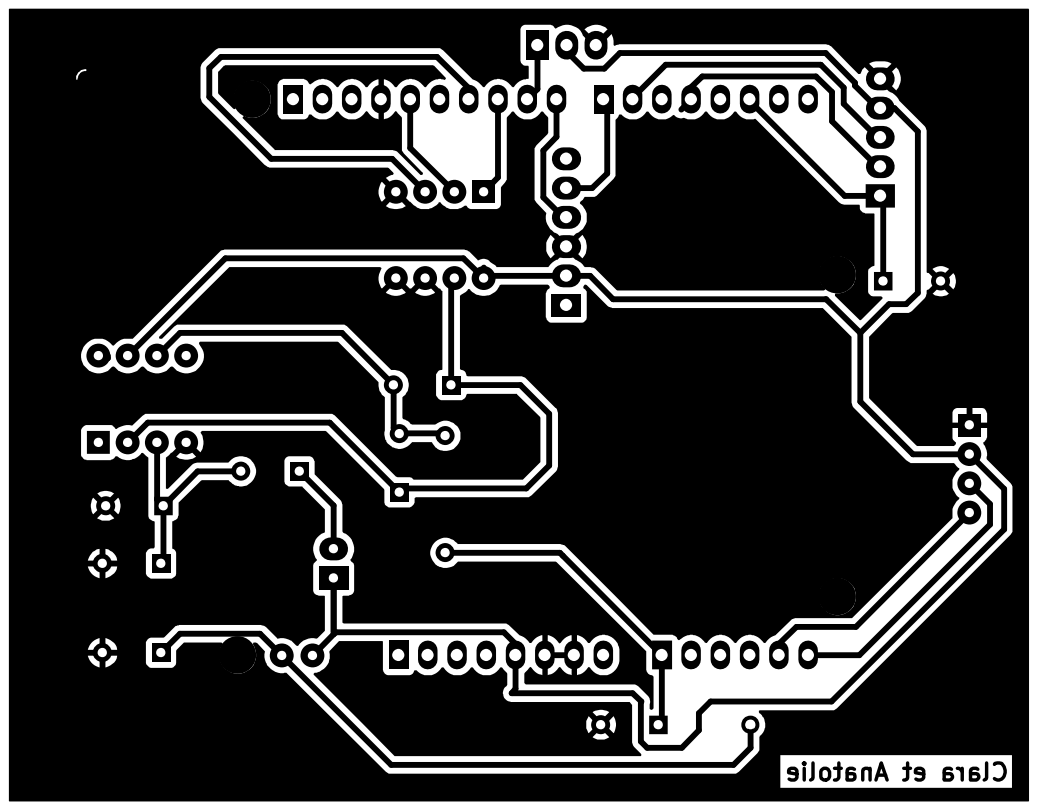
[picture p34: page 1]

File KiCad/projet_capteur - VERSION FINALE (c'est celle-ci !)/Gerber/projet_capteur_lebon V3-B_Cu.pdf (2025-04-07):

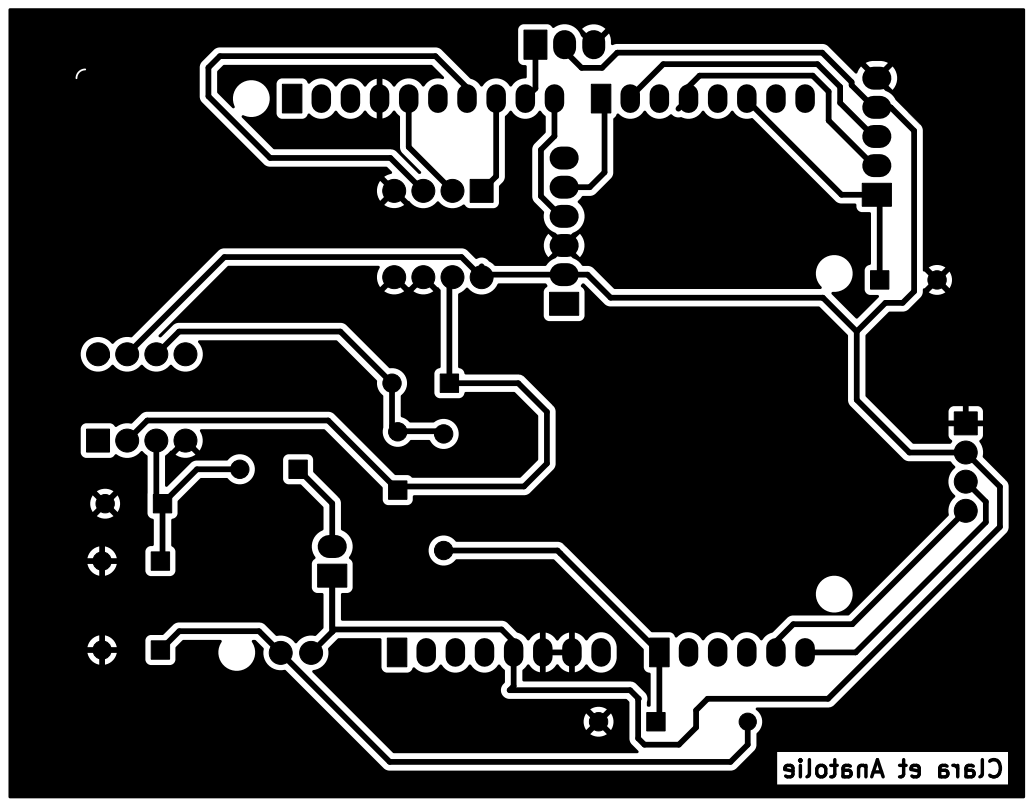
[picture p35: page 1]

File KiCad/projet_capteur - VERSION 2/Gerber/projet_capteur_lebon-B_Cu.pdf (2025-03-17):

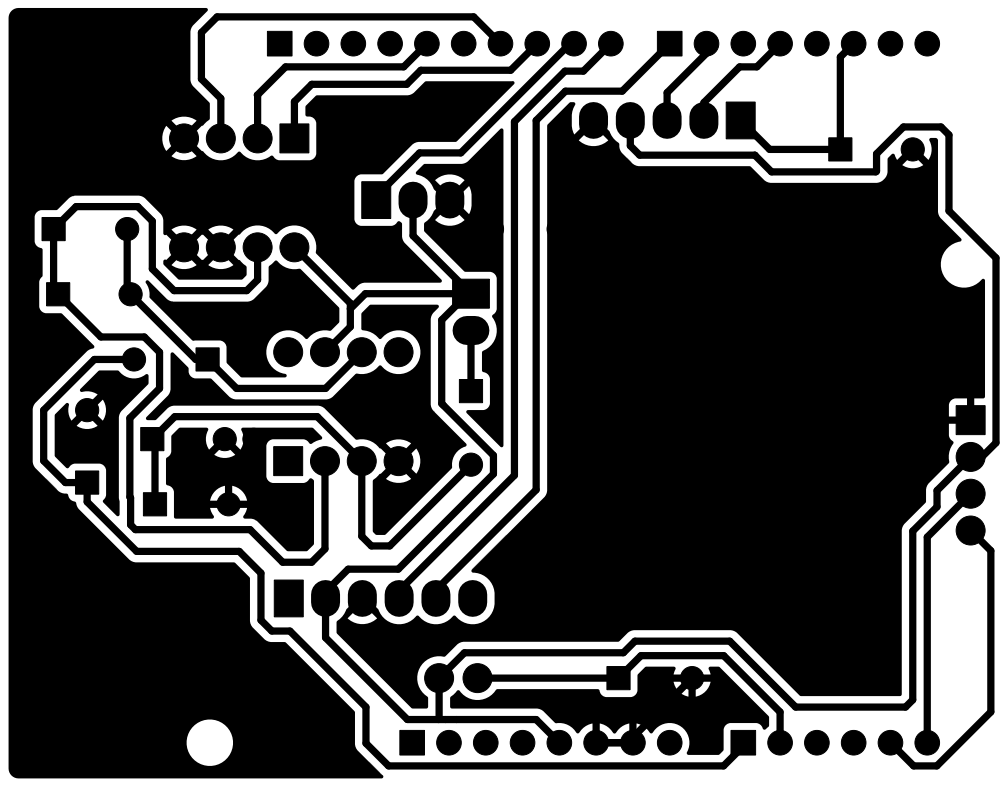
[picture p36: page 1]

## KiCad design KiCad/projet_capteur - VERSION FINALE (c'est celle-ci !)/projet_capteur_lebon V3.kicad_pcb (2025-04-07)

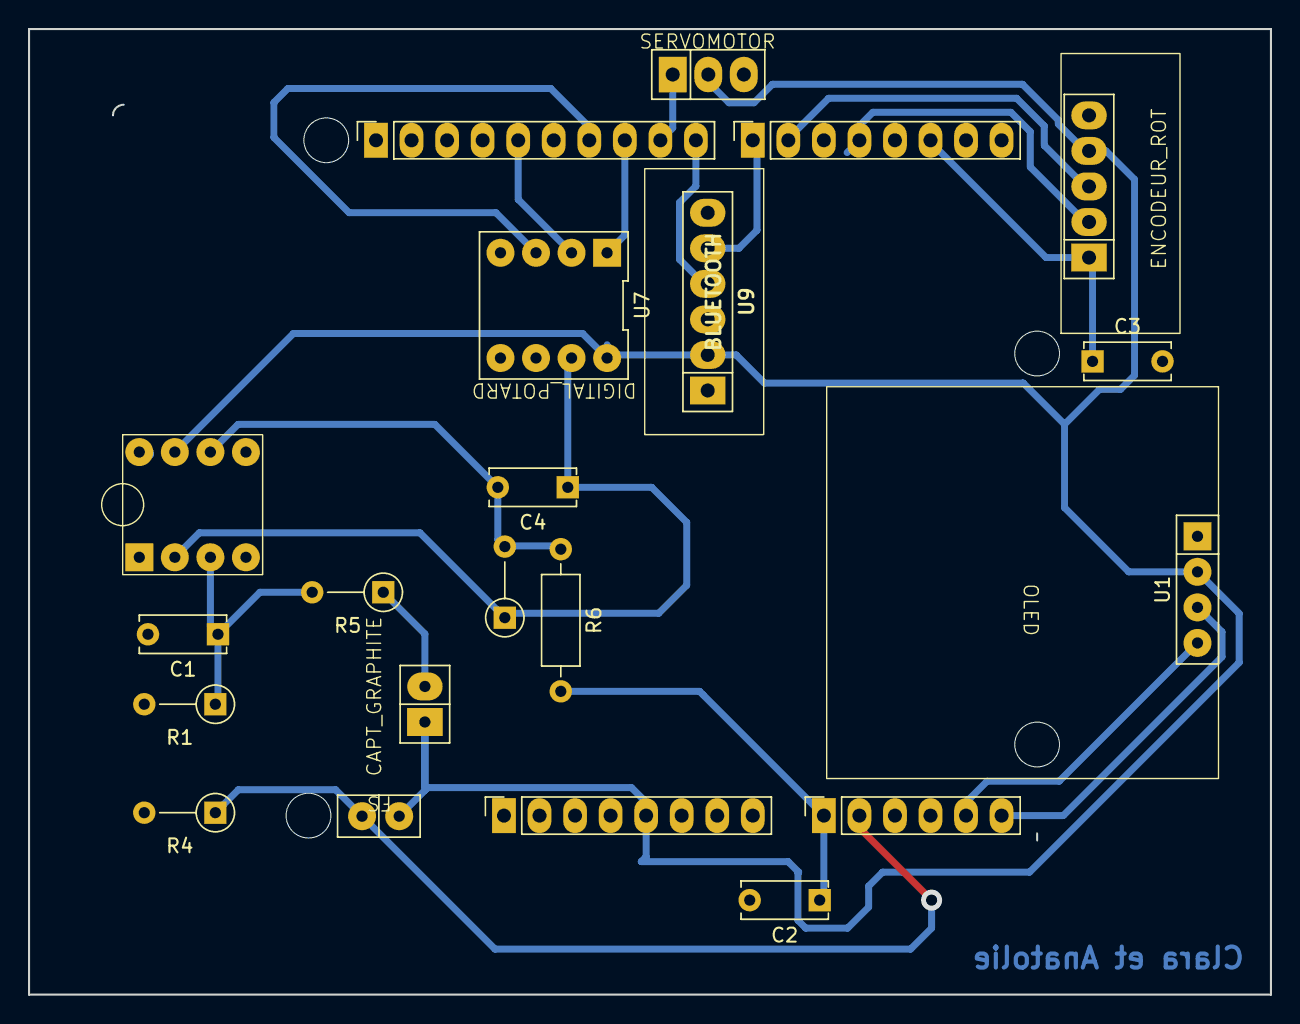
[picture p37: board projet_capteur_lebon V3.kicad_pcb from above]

Board: 2 copper layers, 88.8 x 69.0 mm, 25 parts (0 on the bottom side), 19 nets.

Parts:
C1, C2, C3: 100n; C_Disc_D6.0mm_W2.5mm_P5.00mm
C4: 1u; C_Disc_D6.0mm_W2.5mm_P5.00mm
J1: Power; PinSocket_1x08_P2.54mm_Vertical
J2: Digital/PWM; PinSocket_1x10_P2.54mm_Vertical
J3: Analog; PinSocket_1x06_P2.54mm_Vertical
J4: Digital/PWM; PinSocket_1x08_P2.54mm_Vertical
MH1, MH2, MH3, MH4: MountingHole_3.2mm
R1, R3: 100k; R_Axial_DIN0207_L6.3mm_D2.5mm_P5.08mm_Vertical
R4: 47k; R_Axial_DIN0207_L6.3mm_D2.5mm_P5.08mm_Vertical
R5: 10k; R_Axial_DIN0207_L6.3mm_D2.5mm_P5.08mm_Vertical
R6: 1k; R_Axial_DIN0207_L6.3mm_D2.5mm_P10.16mm_Horizontal
U1: SIP-4
U2: ENCODEUR ROT
U4, U7: DIP-8_296
U5: SIP-2
U6: SIP-3
U8: CAPTEUR_GRAPHITE
U9: BLUETOOTH

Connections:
5V: J1.5, U1.2 (VCC), U2.4 (VCC), U4.7 (VCC+), U5.1 (Vcc), U6.2 (VCC), U7.8 (VCC), U8.1 (VCC), U9.2 (VCC)
/13: J2.5, U7.2 (SCK)
/*9: J2.9, U6.1 (Data)
/*10: J2.8, U7.1 (CS)
/*11: J2.7, U7.3 (SDI)
CAPT_AMPL: C2.1, J3.1, R6.2
CLK: C3.1, J4.6, U2.1 (CLK)
DT: J4.4, U2.2 (DT)
GND: C1.2, C2.2, C3.2, J1.6, J1.7, J2.4, R1.2, R4.2, U1.1 (GND), U2.5 (GND), U4.4 (VCC-), U6.3 (GND), U7.4 (GND), U7.5 (POA), U7.6 (POW), U9.3 (GND)
unnamed: C1.1, R1.1, R5.2, U4.3 (IN+)
unnamed: C4.2, R3.2, R6.1, U4.6 (OUT)
OUT_CAPT: R5.1, U8.2 (OUT_CAPT)
OUT_FLEX: J3.2, R4.1, U5.2 (Out)
R2: C4.1, R3.1, U4.2 (IN-), U7.7 (POB)
RX: J4.1, U9.5 (RX)
SCL: J2.1, J3.6, U1.3 (SCL)
SDA: J2.2, J3.5, U1.4 (SDA)
SW: J4.2, U2.3 (SW)
TXD: J2.10, U9.4 (TXD)

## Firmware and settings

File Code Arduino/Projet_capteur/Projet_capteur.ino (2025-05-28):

//----------------------------Inclusion des bibliothèques--------------------------

#include <SoftwareSerial.h>  //Bluetooth
#include <Servo.h>  //Servomoteur
#include <Wire.h>   //OLED
#include <Adafruit_SSD1306.h>   //OLED
#include <SPI.h>  //Potentiomètre
#include <stdlib.h>

//----------------------------Définitions et constantes------------------------------

  //Bluetooth:
#define rxPin 8
#define txPin 7

  //Encodeur rotatoire:
#define Encodeurclkpin  2  //CLK Output A, avec interruption
#define Encodeurdtpin 4  //DT Output B
#define Encodeurswpin 6   //Switch

  //OLED:
#define nombreDePixelsEnLargeur 128 //Largeur de l'écran OLED, en pixels
#define nombreDePixelsEnHauteur 64  //Hauteur de l'écran OLED, en pixels
#define brocheResetOLED -1  //Reset de l'écran OLED
#define adresseI2CecranOLED 0x3C
#define nb_item 3 //Nombre de choix dans le menu

  //Servomoteur:
#define servopin 9  // pin contrôlant le moteur (pin PWM)

  //Potentiomètre digital:
#define MCP_NOP                 0b00000000
#define MCP_WRITE               0b00010001
#define MCP_SHTDWN              0b00100001

  //Flex sensor:
#define flexPin A1

  //Capteur graphite:
#define graphitepin A0

  //Autres:
#define baudrate 9600

//----------------------------Variables------------------------------------------

  //Bluetooth:
SoftwareSerial mySerial (rxPin, txPin);
//int i=1; 

  //Servomoteur:
Servo myservo;
int Pos_servo = 0;

  //Encodeur:
volatile int Pos_encodeur = 0;
int etat_bouton = 0; // variable pour stocker la lecture de l'etat du bouton
int Menu = 0;

  //Flex sensor:
float val_flexs = 0;
float Vflexs, Rflexs = 0.0;
const float VCC = 5.0;
const float Rdiv = 39000.0;
const float flatres = 25000.0;
const float bentres = 100000.0;

  //Capteur graphite:
unsigned long previousMillis = 0; //Pour conserver le temps passé depuis le dernier appel de millis()
int val_graph = 0;
float VGraph, RGraph = 0.0;
const float R1 = 100000;
const float R3 = 100000;
const float R5 = 10000;

  //OLED:
int choix = 0;
float lastval = -100.0;

  //Potentiomètre digital:
const int csPin = 10;
const int maxPositions = 256;
const long rAB = 47000;
const byte rWiper = 125;
const byte pot0 = 0x11;
const byte pot0shutdown = 0x21;
float R2;

Adafruit_SSD1306 ecranOLED (nombreDePixelsEnLargeur, nombreDePixelsEnHauteur, &Wire, brocheResetOLED);

//----------------------------Setup------------------------------------------

void setup() {

  //Encodeur rotatoire:
  pinMode(Encodeurclkpin, INPUT); 
  digitalWrite(Encodeurclkpin, HIGH);  // Turn on pullup resistor

  pinMode(Encodeurdtpin, INPUT); 
  digitalWrite(Encodeurdtpin, HIGH);  // Turn on pullup resistor

  pinMode(Encodeurswpin, INPUT); 
  digitalWrite(Encodeurswpin, HIGH);  // Turn on pullup resistor

  attachInterrupt(0, doEncoder, RISING); // On met une interruption sur l'encodeur

  //Module Bluetooth:
  pinMode (rxPin,INPUT);
  pinMode (txPin,OUTPUT);

  mySerial.begin(baudrate);
  Serial.begin(9600);

  //Servomoteur:
  myservo.attach(servopin);

  //Flex Sensor:
  pinMode(flexPin, INPUT);

  //Capt graphite:
  //pinMode(graphitepin, INPUT);

  //OLED:
  if (!ecranOLED.begin (SSD1306_SWITCHCAPVCC, adresseI2CecranOLED)) // Arrêt du programme (boucle infinie) si échec d'initialisation
    while(1);

  ecranOLED.clearDisplay();

  //Digital Potentiometre:
  pinMode (csPin, OUTPUT); //select pin output
  digitalWrite(csPin, HIGH); //SPI chip disabled
  pinMode (csPin, INPUT);
  SPI.begin();

  //Calibration();
  setPotWiper(pot0, 0);

  delay(500);

  //Pour indiquer qu'on démarre:
  Serial.println(F("Let's go"));

}

//----------------------------Loop------------------------------------------

void loop() {

  Afficher_Menu();
  //Serial.println("OK");
  
  //char someChar[32]={0};

  /*if (Serial.available()>0){
    instr[i++]=Serial.read();
  }*/

  /*while (Serial.available()){
    do{
      someChar[i++] = Serial.read();
    delay(3);
    }while (Serial.available()>0);

    mySerial.println(someChar);
    Serial.println(someChar);
  }
  while (mySerial.available()){
    Serial.print((char)mySerial.read());
  }  */

}

//----------------------------Fonctions------------------------------------------

// Renvoie la valeur de la résisatnce aux bornes du flex sensor

float flexSensor() {
  char val_envoi[20];

  float ADCflex = analogRead(flexPin);
  Vflexs = ADCflex * VCC / 1024.0;
  Rflexs = Rdiv * (VCC / Vflexs - 1.0);

  dtostrf(Rflexs, sizeof(val_envoi)-1, 0, val_envoi);
  mySerial.write(val_envoi);
  delay(500);
  return Rflexs;
}

// Renvoie la valeur de la résisatnce aux bornes du capteur graphite

float graphiteSensor() {
  float ADCgraph = analogRead(graphitepin); //changement de pin
  float VGraph = ADCgraph * VCC / 1024.0;
  
  RGraph = Rdiv*(VCC/VGraph-1); 
  return RGraph;
}

// Renvoie la valeur de la tension aux bornes du capteur graphite

float graphiteSensor_voltage() {
  float ADCgraph = analogRead(graphitepin); //changement de pin
  float VGraph = ADCgraph * VCC / 1024.0; 

  return VGraph;
}

// Règle la résistance de sortie du potentiomètre digital

void setPotWiper(int addr, int pos) {
  pos = constrain(pos, 0, 255);
  digitalWrite(csPin, LOW);
  SPI.transfer(addr);
  SPI.transfer(pos);
  digitalWrite(csPin, HIGH);

  R2 = ((rAB * pos) / maxPositions) + rWiper;
}

// Calibre le potentiomètre digital pour avoir une tensoin de 3V avec une tolérance de 0.15V

void Calibration() {
  float target = 3.0, tol = 0.15;
  int pos = 0;
  char chaine[10];

  do {
    setPotWiper(pot0, pos);
    pos += 5;
    delay(200);
  } while ((graphiteSensor_voltage() < (target - tol) || graphiteSensor_voltage() > (target + tol)) && pos <= 265);
  
  dtostrf(pos, sizeof(chaine)-1, 2, chaine);
  
  if (pos < 265) {
    Serial.println(F("Potentiometer calibrated at position : "));
    Serial.print(chaine);

    float val = graphiteSensor();
    dtostrf(val, sizeof(chaine)-1, 2, chaine);
    Serial.println(F("Value : "));
    Serial.print(chaine);
  }
  else {
    Serial.println(F("Potentiometer not calibrated at target 3V"));
    //dtostrf(pos, sizeof(chaine)-1, 2, chaine);
    //Serial.print(chaine);
  }
} 

// Lit la position de l'encodeur, utilisée lors de l'interruption

void doEncoder() {
  if ( (digitalRead(Encodeurclkpin)==HIGH) && (digitalRead(Encodeurdtpin)==HIGH) ) { 
    Pos_encodeur++;
  } 
  else if ( (digitalRead(Encodeurclkpin)==HIGH) && (digitalRead(Encodeurdtpin)==LOW) ) {  //
    Pos_encodeur--;
  }  
}

// Vérifie l'état du bouton de l'endodeur rotatoire

void appui_bouton (){
  etat_bouton = digitalRead(Encodeurswpin);
  if (etat_bouton == 0) {
    if (Menu == 0) {
      Menu++;
    }
    else {
      Menu--;
    }
  }
  // Serial.println(etat_bouton, DEC);
  // Serial.println(Menu, DEC);
}

// Affiche le menu sur l'écran OLED et les actions associées

void Afficher_Menu (){
  unsigned long currentMillis = millis ();  // Sauvegarde la valeur du temps écoulé depuis le lancement du programme
  float valeur;
  char place[20];

  if (currentMillis - previousMillis >= 500){
    previousMillis = currentMillis;

    appui_bouton();
    choix = Pos_encodeur % nb_item;

    switch (abs(choix)){
      case 0 :
        if (Menu == 0) {
          ecranOLED.clearDisplay();   // Effaçage de l'intégralité du buffer
          ecranOLED.setTextSize(2);   // Taille du texte
          ecranOLED.setCursor(0, 0);
          ecranOLED.setTextColor (SSD1306_WHITE, SSD1306_BLACK);  // Met le texte en blanc et le fond en noir
          ecranOLED.println (F("*MENU*"));
          ecranOLED.setTextSize(1);
          ecranOLED.setTextColor(SSD1306_BLACK, SSD1306_WHITE);
          ecranOLED.println(F("Flex Sensor")); // Ecrit le premier choix du menu comme en "surbrillance"...
          ecranOLED.setTextColor(SSD1306_WHITE, SSD1306_BLACK);
          ecranOLED.println(F("Graphite Sensor")); // ... et le reste normalement
          ecranOLED.println(F("Servomoteur"));
          ecranOLED.display();
        }
        else if (Menu == 1) {
          ecranOLED.clearDisplay();   // Effaçage de l'intégralité du buffer
          ecranOLED.setTextSize(2);   // Taille du texte
          ecranOLED.setCursor(0, 0);
          ecranOLED.setTextColor (SSD1306_WHITE, SSD1306_BLACK);
          ecranOLED.println (F("*Menu 1*")); 
          ecranOLED.setTextSize(1);
          ecranOLED.println (F("FlexSensor :"));
          ecranOLED.setTextSize(1);
          valeur = flexSensor ();
          dtostrf(valeur, sizeof(place)-1, 2, place);
          ecranOLED.println (place);
          ecranOLED.display();
        }
        break;

      case 1:
          if (Menu == 0) {
            ecranOLED.clearDisplay();   // Effaçage de l'intégralité du buffer
            ecranOLED.setTextSize(2);   // Taille du texte
            ecranOLED.setCursor(0, 0);
            ecranOLED.setTextColor (SSD1306_WHITE, SSD1306_BLACK);
            ecranOLED.println (F("*MENU*"));
            ecranOLED.setTextSize(1);
            ecranOLED.setTextColor(SSD1306_WHITE, SSD1306_BLACK);
            ecranOLED.println(F("Flex Sensor"));
            ecranOLED.setTextColor(SSD1306_BLACK, SSD1306_WHITE);
            ecranOLED.println(F("Graphite Sensor"));
            ecranOLED.setTextColor(SSD1306_WHITE, SSD1306_BLACK);
            ecranOLED.println(F("Servomoteur"));
            ecranOLED.display();
          }

          else if (Menu == 1) {
            ecranOLED.clearDisplay();   // Effaçage de l'intégralité du buffer
            ecranOLED.setTextSize(2);   // Taille du texte
            ecranOLED.setCursor(0, 0);
            ecranOLED.setTextColor (SSD1306_WHITE, SSD1306_BLACK);
            ecranOLED.println (F("*Menu 2*")); 
            ecranOLED.setTextSize(1);
            ecranOLED.println (F("Graphite Sensor :")); 
            ecranOLED.setTextSize(1);

            valeur = graphiteSensor();
            dtostrf(valeur, sizeof(place)-1, 2, place);
            ecranOLED.println (place); 
            ecranOLED.display();
          }
        break;

      case 2:
        if (Menu == 0) {
          ecranOLED.clearDisplay();   // Effaçage de l'intégralité du buffer
          ecranOLED.setTextSize(2);   // Taille du texte
          ecranOLED.setCursor(0, 0);
          ecranOLED.setTextColor (SSD1306_WHITE, SSD1306_BLACK);
          ecranOLED.println (F("*MENU*"));
          ecranOLED.setTextSize(1);
          ecranOLED.setTextColor(SSD1306_WHITE, SSD1306_BLACK);
          ecranOLED.println(F("Flex Sensor"));
          ecranOLED.println(F("Graphite Sensor"));
          ecranOLED.setTextColor(SSD1306_BLACK, SSD1306_WHITE);
          ecranOLED.println(F("Servomoteur"));
          ecranOLED.display();
        }
        else if (Menu == 1){
          ecranOLED.clearDisplay();   // Effaçage de l'intégralité du buffer
          ecranOLED.setTextSize(2);   // Taille du texte
          ecranOLED.setCursor(0, 0);
          ecranOLED.setTextColor (SSD1306_WHITE, SSD1306_BLACK);
          ecranOLED.println (F("*Menu 3*")); 
          ecranOLED.setTextSize(1);
          ecranOLED.println (F("Servomoteur :")); 
          ecranOLED.setTextSize(1);

          val_flexs=flexSensor();

          if ((abs(val_flexs - lastval))>10){
            //Serial.println (val_flexs);

            if ((val_flexs>34000.0)&&(val_flexs<180000.0)){
              Pos_servo = (val_flexs/112000)*180;
              myservo.write(Pos_servo);
              //Serial.println (Pos_servo);
              dtostrf(Pos_servo, sizeof(place)-1, 2, place);
              ecranOLED.println (place); 
              ecranOLED.display();
              //Serial.println (place);
            }
            else {
              ecranOLED.println ("Verifier la valeur du flex sensor");
              ecranOLED.display();

            }
          }

          lastval=val_flexs;
          

        }
        break;
    }
  }
}

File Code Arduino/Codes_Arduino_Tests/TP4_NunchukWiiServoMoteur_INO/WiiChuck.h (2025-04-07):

/*
 * Nunchuck -- Use a Wii Nunchuck
 * Tim Hirzel http://www.growdown.com
 * 
 notes on Wii Nunchuck Behavior.
 This library provides an improved derivation of rotation angles from the nunchuck accelerometer data.
 The biggest different over existing libraries (that I know of ) is the full 360 degrees of Roll data
 from teh combination of the x and z axis accelerometer data using the math library atan2. 

 It is accurate with 360 degrees of roll (rotation around axis coming out of the c button, the front of the wii),
 and about 180 degrees of pitch (rotation about the axis coming out of the side of the wii).  (read more below)

 In terms of mapping the wii position to angles, its important to note that while the Nunchuck
 sense Pitch, and Roll, it does not sense Yaw, or the compass direction.  This creates an important
 disparity where the nunchuck only works within one hemisphere.  At a result, when the pitch values are 
 less than about 10, and greater than about 170, the Roll data gets very unstable.  essentially, the roll
 data flips over 180 degrees very quickly.   To understand this property better, rotate the wii around the
 axis of the joystick.  You see the sensor data stays constant (with noise).  Because of this, it cant know
 the difference between arriving upside via 180 degree Roll, or 180 degree pitch.  It just assumes its always
 180 roll.


 * 
 * This file is an adaptation of the code by these authors:
 * Tod E. Kurt, http://todbot.com/blog/
 *
 * The Wii Nunchuck reading code is taken from Windmeadow Labs
 * http://www.windmeadow.com/node/42
 */

#ifndef WiiChuck_h
#define WiiChuck_h

//#include "WProgram.h" 
#include "Arduino.h" 
#include <Wire.h>
#include <math.h>


// these may need to be adjusted for each nunchuck for calibration
#define ZEROX 510  
#define ZEROY 490
#define ZEROZ 460
#define RADIUS 210  // probably pretty universal

#define DEFAULT_ZERO_JOY_X 127
#define DEFAULT_ZERO_JOY_Y 127

#define AVERAGE_N 25


class WiiChuck
{
  private:
      byte cnt;
      uint8_t status[6];		// array to store wiichuck output
      byte averageCounterP;
      byte averageCounterR;
      int Pitch[AVERAGE_N];
      int Roll[AVERAGE_N];
      int i;
      int total;
      uint8_t zeroJoyX;   // these are about where mine are
      uint8_t zeroJoyY; // use calibrateJoy when the stick is at zero to correct
      int lastJoyX;
      int lastJoyY;
      int angles[3];

      boolean lastZ, lastC;

  public:
    byte joyX;
    byte joyY;
    boolean buttonZ;
    boolean buttonC;
    void begin() 
    {
      Wire.begin();
      cnt = 0;
      averageCounterP = 0;
      averageCounterR = 0;
      // instead of the common 0x40 -> 0x00 initialization, we
      // use 0xF0 -> 0x55 followed by 0xFB -> 0x00.
      // this lets us use 3rd party nunchucks (like cheap $4 ebay ones)
      // while still letting us use official oness.
      // only side effect is that we no longer need to decode bytes in _nunchuk_decode_byte
      // see http://www.arduino.cc/cgi-bin/yabb2/YaBB.pl?num=1264805255
      //  
      Wire.beginTransmission(0x52);	// device address
      Wire.write(0xF0);
      Wire.write(0x55);
      Wire.endTransmission();
      delay(1);
      Wire.beginTransmission(0x52);
      Wire.write(0xFB);
      Wire.write(0x00);
      Wire.endTransmission();
      update();            
      for (i = 0; i<3;i++)
      {
        angles[i] = 0;
      }
      zeroJoyX = DEFAULT_ZERO_JOY_X;
      zeroJoyY = DEFAULT_ZERO_JOY_Y;
    }


    void calibrateJoy()
    {
      zeroJoyX = joyX;
      zeroJoyY = joyY;
    }

    void update()
    {
      Wire.requestFrom (0x52, 6);	// request data from nunchuck
      while (Wire.available ())
      {
        // receive byte as an integer
        status[cnt] = _nunchuk_decode_byte (Wire.read()); //
        cnt++;
      }
      if (cnt > 5)
      {
        lastZ = buttonZ;
        lastC = buttonC;
        lastJoyX = readJoyX();
        lastJoyY = readJoyY();

        cnt = 0;
        joyX = (status[0]);
        joyY = (status[1]);
        for (i = 0; i < 3; i++)
        { 
          angles[i] = (status[i+2] << 2) + ((status[5] & (B00000011 << ((i+1)*2) ) >> ((i+1)*2))); 
        }

        buttonZ = !( status[5] & B00000001);
        buttonC = !((status[5] & B00000010) >> 1);
        _send_zero(); // send the request for next bytes

      }
    }


    // UNCOMMENT FOR DEBUGGING
    //byte * getStatus() {
    //    return status;
    //}

    float readAccelX()
    {
      return (float)angles[0]- ZEROX;
    }
    float readAccelY()
    {
      return (float)angles[1]- ZEROY;
    }
    float readAccelZ()
    {
      return (float)angles[2]- ZEROZ;
    }

    boolean zPressed()
    {
      return (buttonZ && ! lastZ);
    }
    boolean cPressed()
    {
      return (buttonC && ! lastC);
    }

    // for using the joystick like a directional button
    boolean rightJoy(int thresh=60)
    {
      return (readJoyX() > thresh and lastJoyX <= thresh);
    }

    // for using the joystick like a directional button
    boolean leftJoy(int thresh=60)
    {
      return (readJoyX() < -thresh and lastJoyX >= -thresh);
    }


    int readJoyX()
    {
      return (int) joyX - zeroJoyX;
    }

    int readJoyY()
    {
      return (int)joyY - zeroJoyY;
    }


    // R, the radius, generally hovers around 210 (at least it does with mine)
    //int R() {
    //    return sqrt(readAccelX() * readAccelX() +readAccelY() * readAccelY() + readAccelZ() * readAccelZ());  
    //}


    // returns roll degrees
    int readRoll()
    {
      //return (int)(atan2(readAccelX(),readAccelZ())/ M_PI * 180.0);
      averageCounterR ++;
      if (averageCounterR >= AVERAGE_N)
      {
        averageCounterR = 0;
      }
      
      Roll[averageCounterR] = (int) (atan2(readAccelX(),readAccelZ())/ M_PI * 180.0);
      
      total = 0;
      for( i = 0 ; i < AVERAGE_N ; i++)
      {
         total = total + Roll[i];
      }
        
      return (total /AVERAGE_N);
    }

    // returns pitch in degrees
    int readPitch()
    {
      averageCounterP ++;
      if (averageCounterP >= AVERAGE_N)
      {
        averageCounterP = 0;
      }
      
      Pitch[averageCounterP] = (int) (acos(readAccelY()/RADIUS)/ M_PI * 180.0);  // optionally swap 'RADIUS' for 'R()'
      
      total = 0;
      for( i = 0 ; i < AVERAGE_N ; i++)
      {
         total = total + Pitch[i];
      }
        
      return (total /AVERAGE_N);
    }

  private:
    byte _nunchuk_decode_byte (byte x)
    {
      //decode is only necessary with certain initializations 
      //x = (x ^ 0x17) + 0x17;
      return x;
    }

    void _send_zero()
    {
      Wire.beginTransmission (0x52);	// transmit to device 0x52
      Wire.write (0x00);		// sends one byte
      Wire.endTransmission ();	// stop transmitting
     }

};


#endif

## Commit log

2025-03-17 new repository sur mosh insa
    [Cap_Rect.step, Crocodile Clip & Black Insulator.STEP, Crocodile Clip & RED Insulator .STEP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]
2025-03-17 version 2
    [projet_capteur_lebon.kicad_pcb, projet_capteur_lebon.kicad_sch]
2025-03-19 version 3 en cours
    [projet_capteur_lebon V3.kicad_pcb, projet_capteur_lebon.kicad_pcb, projet_capteur_lebon.kicad_sch]
2025-03-19 fin V3
    [projet_capteur_lebon V3.kicad_pcb, projet_capteur_lebon V3.kicad_sch]
2025-03-19 version finale validee par cathy qui sera imprimee
    [projet_capteur_lebon V3.kicad_pcb]
2025-03-25 init code arduino
2025-03-25 servo et encodeur arduino
2025-04-02 ajout codes arduino cours et avancement code
2025-04-07 jsp ce que c'est mais j'ai ça
2025-04-07 creations dossier photos avec photos dedans et modif vue 3D
    [projet_capteur_lebon V3.kicad_pcb]
2025-04-14 ajout readme et recup tests bench
    [Test-Bench(1).xlsx, projet_capteur_lebon V3.kicad_sch]
2025-04-15 arduino avancées
2025-05-06 code pour banc de test
2025-05-08 ajout mesures
    [mesures capteurs v1.xlsx]
2025-05-13 ajt servo + debut com
2025-05-18 avancement readme + fin arduino
2025-05-19 fin code avec servo
2025-05-19 ajout datasheet + mise en forme git
    [Test-Bench(1).xlsx, mesures capteurs v1.xlsx]
2025-05-19 avancement readme
    [Mesures_Capteur_Graphite.xlsx]
2025-05-21 excel banc de test jsp quoi
    [Mesures_Capteur_Graphite.xlsx]
2025-05-28 dernieres modifs
    [projet_capteur_lebon V3.kicad_pcb, projet_capteur_lebon V3.kicad_sch, projet_capteur_lebon.kicad_pcb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]
